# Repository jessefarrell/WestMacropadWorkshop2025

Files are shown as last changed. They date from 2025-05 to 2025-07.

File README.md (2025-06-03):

# WestMacropadWorkshop2025
This repository is intended to guide the user through the design of a small Macropad using KiCAD for schematic capture and PCB layout, fusion 360 for enclosure design, and QMK as the foundation for firmware. Students should be guided through the material by an instructor, there's not enough info for this repository to stand on its own (yet)

<em><strong>IMPORTANT NOTE</STRONG></em> - Bad Symbol
-
I made a <strong>mistake</strong> in the 0_west_symbol library provided during workshop #2. Please <u><strong>follow these steps to correct the NMOS symbol.</strong></u> If you do not complete these steps, pin 3 and 1 of the mosfet will be backwards.

1) Download the corrected symbol library
    - Go to <a href="https://github.com/jessefarrell/WestMacropadWorkshop2025/blob/main/kicad_libraries/0_west_symbols.kicad_sym">design_documents/0_west_symbols.kicad_sym</a> in the github repo and download the file
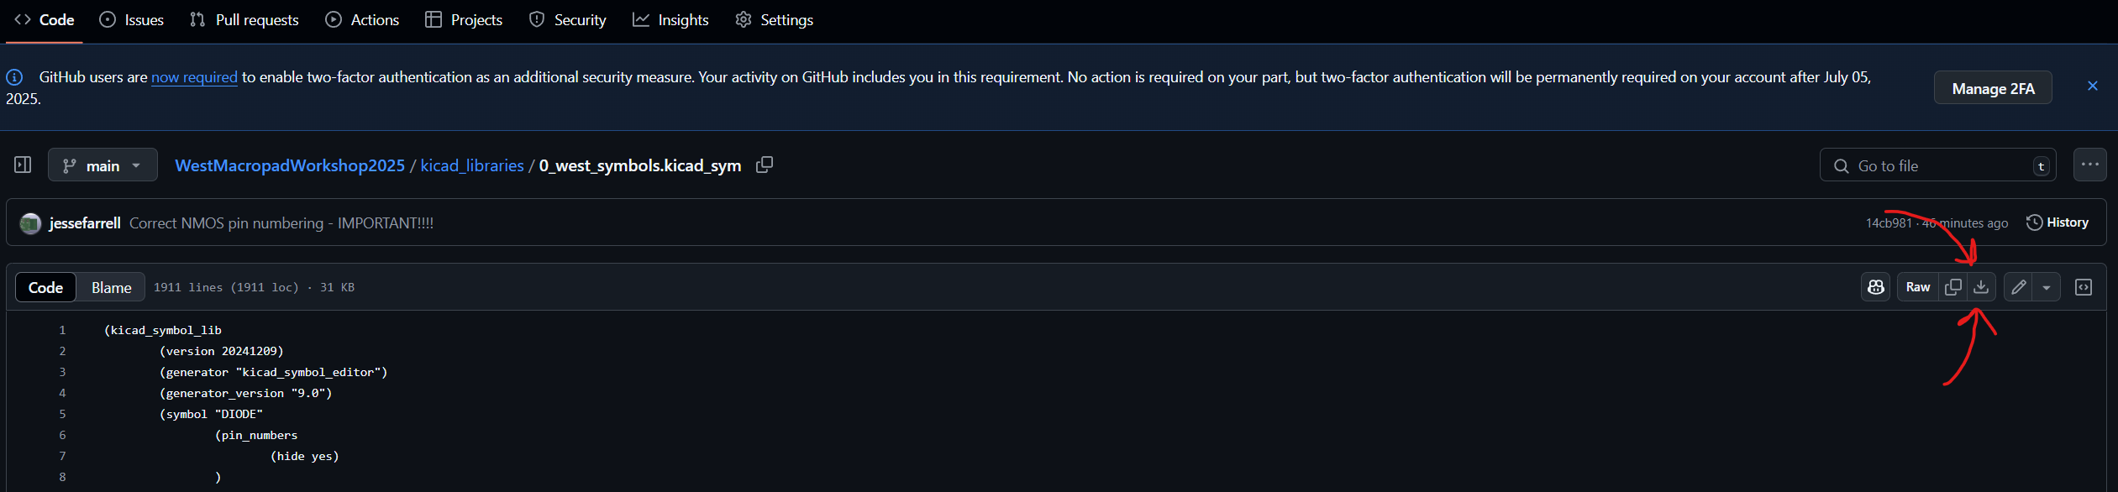
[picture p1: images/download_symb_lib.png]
Download symbol library
    - 
2) Replace <em>0_west_symbols.kicad_sym</em> in your project
    - Navigate to \WestMacropadWorkshop2025\kicad_libraries in your active project directory (not github)
    - Copy the file you downloaded in step 1 into kicad_libraries
    - Select <strong><u>replace the file in the destination</u></strong>
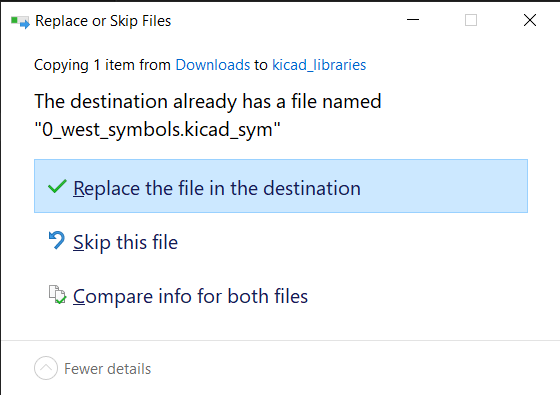
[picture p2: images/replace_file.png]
    - 

3) Sanity Check, & Update Symbol
    - If you've already placed the symbol, you'll have to tell KiCad to reload it
    - To do this <strong>*right-click*</strong> the symbol and go to "Update Symbol" The below window should pop up
    - Select the "Update symbols matching library identifier", and then "Select All" the fields... finally hit <strong>Update</strong>
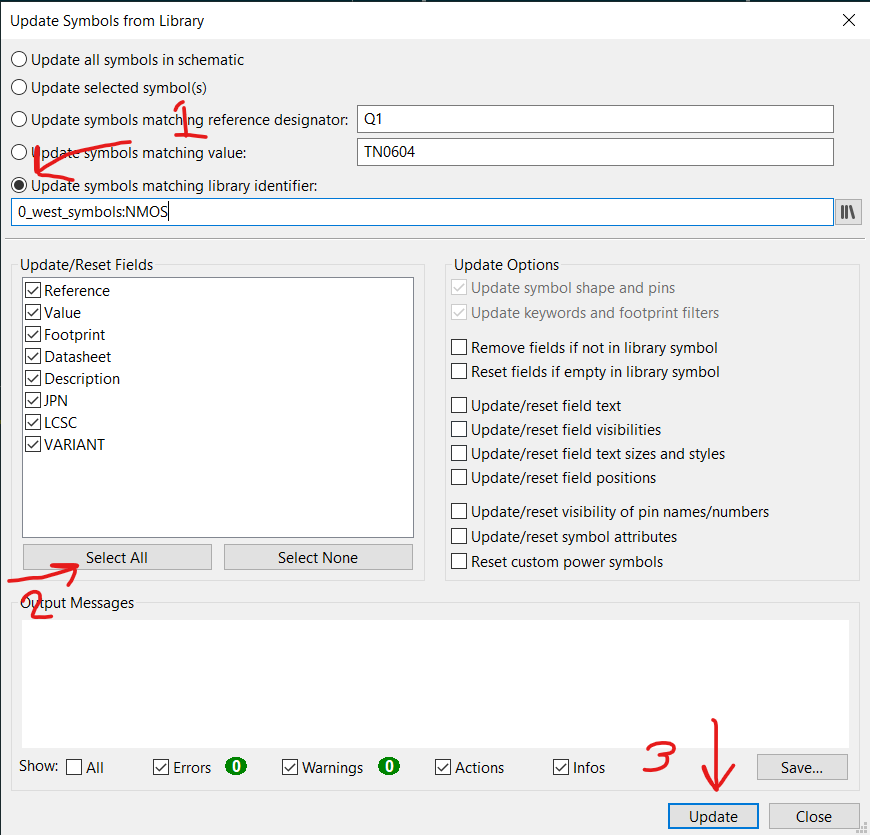
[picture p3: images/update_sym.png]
    - 
    - Once the symbol is updated it should look like this (see below)... pin 3 on top and pin 1 on the bottom 
    - If you odn't see the pin numbers you can enable them using <strong>*right-click*</strong> -> Properties -> Show Pin Numbers
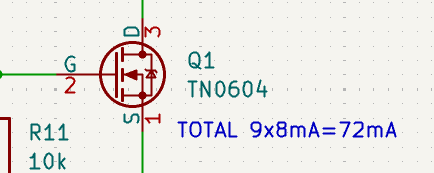
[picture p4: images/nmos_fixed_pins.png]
    - 

Workshop 3 - PCB Layout 
-
> PCB Workshop is primarily outlined in an external document. Several useful files for workshop 3 are stored in this repository.
- Basic Macropad Board Outline - <a href="https://github.com/jessefarrell/WestMacropadWorkshop2025/blob/main/design_documents/Basic_PCB_outline.dxf">/design_documents/Basic_PCB_outline.dxf</a>
    - The "dxf" file is a mechanical file that helps specify locations of critical components for the enclosure... such as key switches, the Pi Pico Development board, and screw holes
- Backup Reference Design - <a href="https://github.com/jessefarrell/WestMacropadWorkshop2025/releases/tag/Workshop%233-Start">Workshop#3 - Blank PCB</a>
    - Hopefully everyone is bringing in their own <em>custom</em> schematic from workshop 2... If not, students can always fall back on the reference design
    - Download the "source code (zip)" from the above link <strong>only if you need to</strong>  
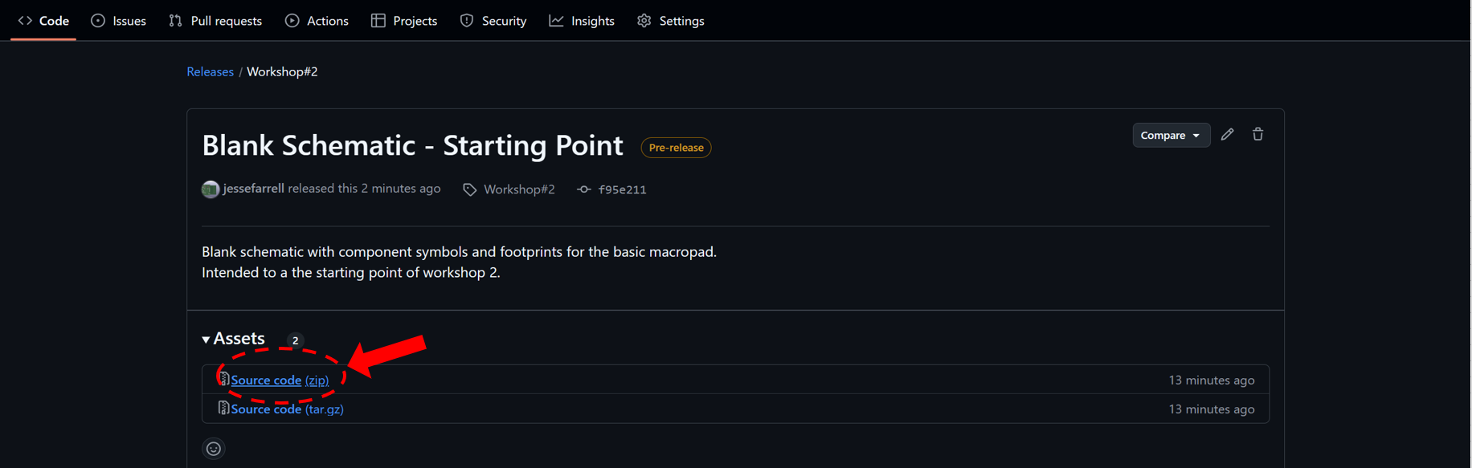
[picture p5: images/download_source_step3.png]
    - 
- New Footprints - <a href="https://github.com/jessefarrell/WestMacropadWorkshop2025/tree/main/kicad_libraries/0_west_footprints.pretty">kicad_libraries/0_west_footprints.pretty</a>
    - I've added some Schneider and WEST logos to the 0_west_footprints library

Workshop 2 - Schematic
-
> Step by step instructions to be followed during the workshop.
1) Copy WestMacropadWorkshop2025 Workshop#2 to your local machine
    - We'll learn more about github & version control later :)
    - Download the "source code (zip)" from here the github repo -> <a href="https://github.com/jessefarrell/WestMacropadWorkshop2025/releases/tag/Workshop%232-start">WestMacropadWorkshop2025</a>
    - KiCad v9 Homepage
    - Extract the contents somewhere on your machine

2) Open **WestMacropadWorkshop2025/west_workshop_2025.kicad_pro**
    - This should automatically launch kicad 9
    - If not launch kicad 9 manually, and then go *File->Open Existing Project* and navigate to the above **kicad_pro** file
3) Double click **west_workshop_2025.kicad_sch** or launch the **Schematic Editor**
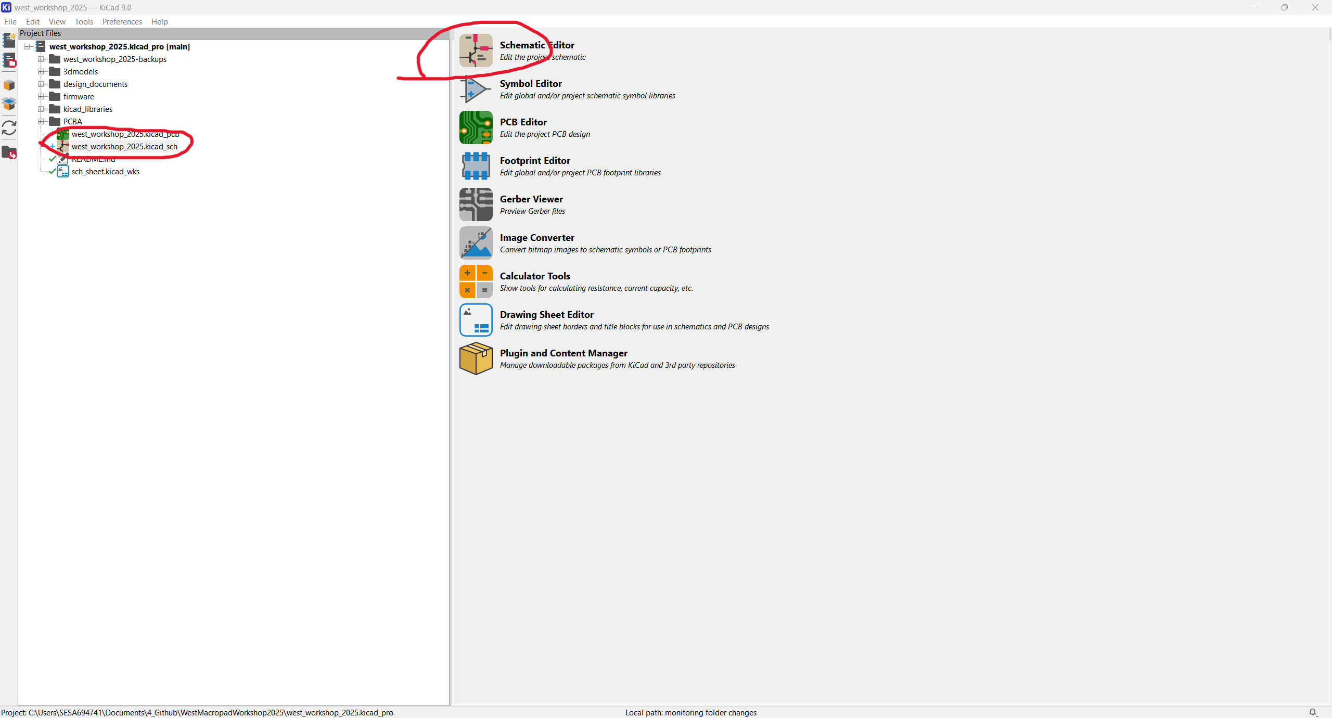
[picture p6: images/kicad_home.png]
KiCad v9 Homepage
    - 

4) Your screen hopfully looks like this. You should be on Kicad v9 or higher.
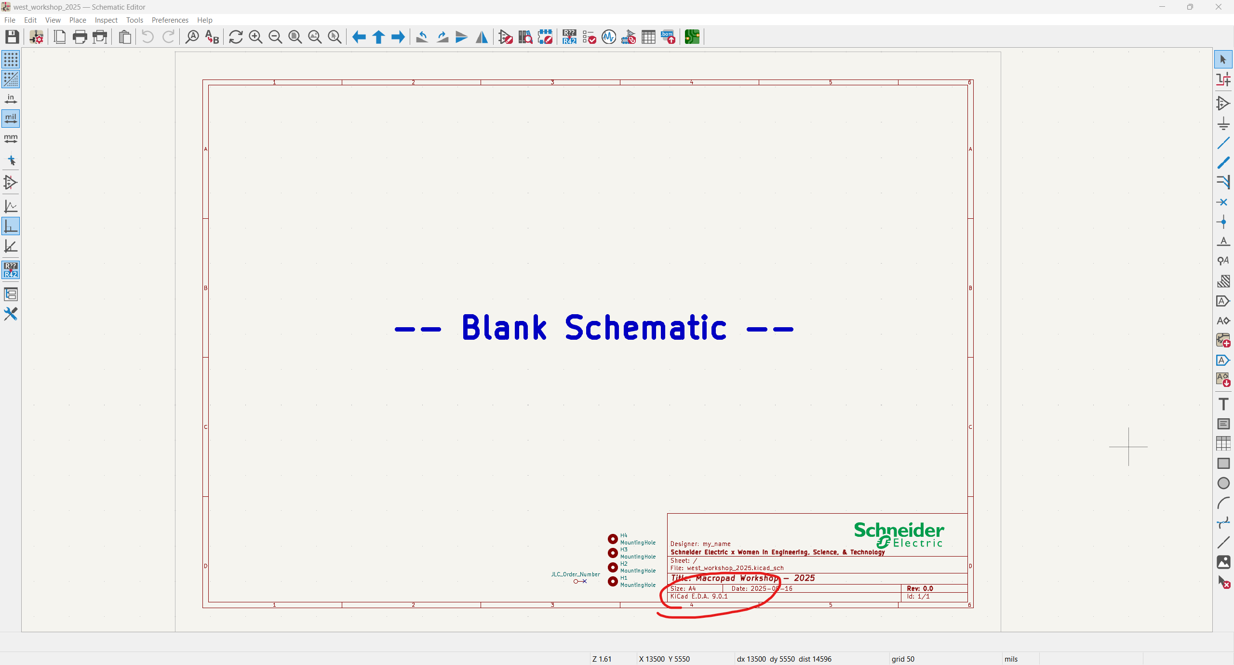
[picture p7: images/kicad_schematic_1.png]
KiCad v9 Schematic
    - 

5) Import WEST libaries (**Optional, but Useful for 3D Visualization**)
    - Symbols and footprints are already configured for the basic macropad
    - Only **the 3D models will be missing** by default
    - If you skip this step now, you may have to do it in workshop 3 or 4
    - First we'll need to import a third party plugin to get the 3d models for the switches
        - Launch the "Plugin and Content Manager"
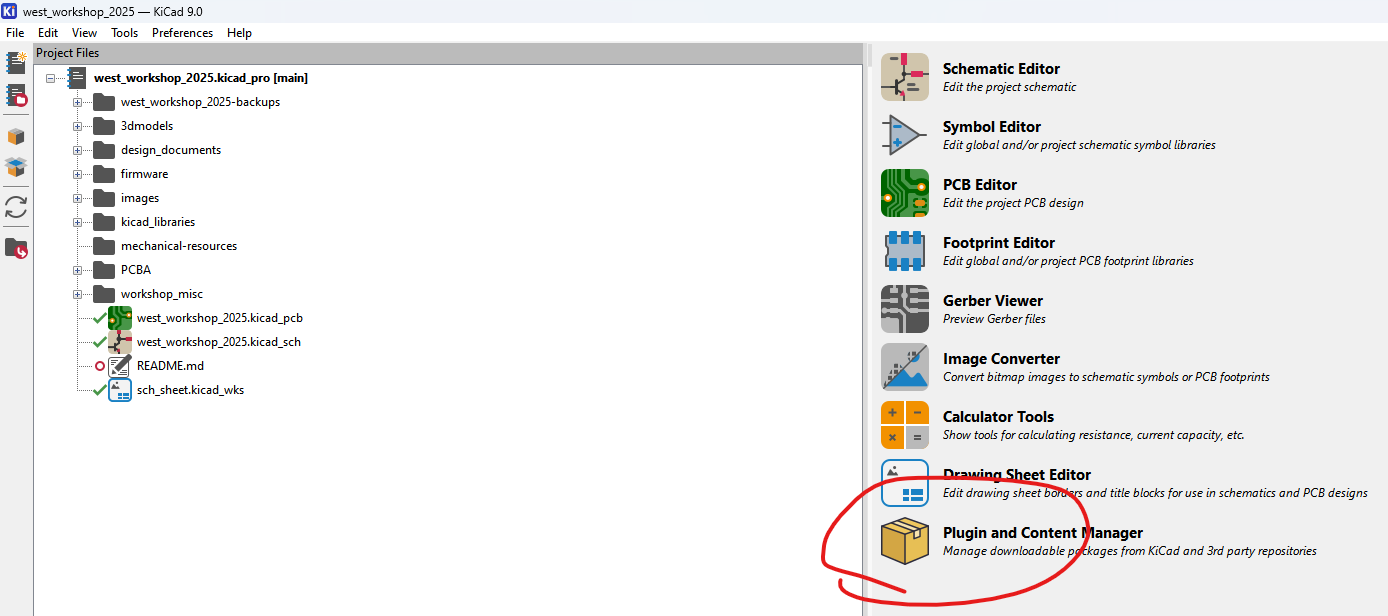
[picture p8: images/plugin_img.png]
        - 
        - Next navigate to "Repository", and "Libraries" shown below. Install the "Keyswitch Kicad Library", and then hit "Apply Pending Changes"
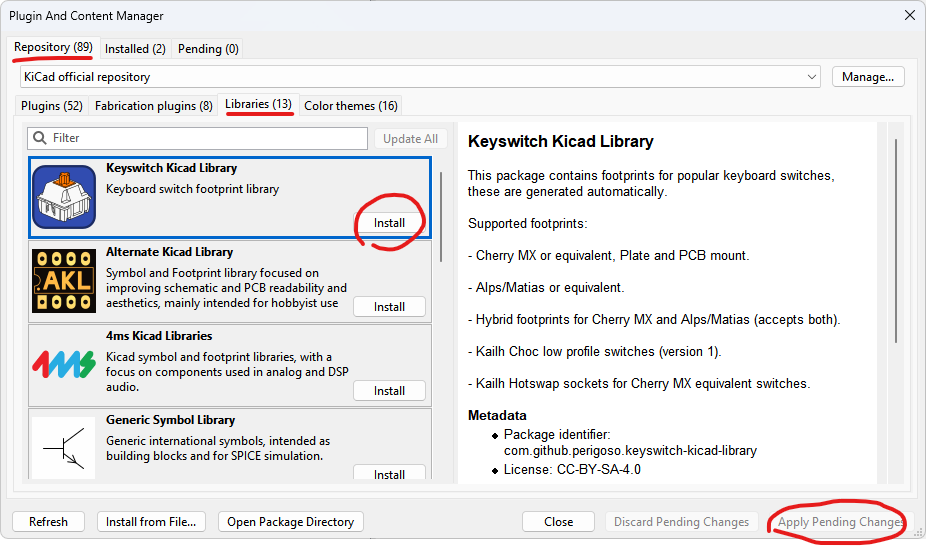
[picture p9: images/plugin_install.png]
        - 
    - Next we're going to go back to the project homepage where we started and launch the **PCB Editor** then go **Preferences->Configure Paths...**
    - Add the following name and path
        - Name: KICAD_USER_3DMODEL_DIR
        - Path: ${KIPRJMOD}\3dmodels
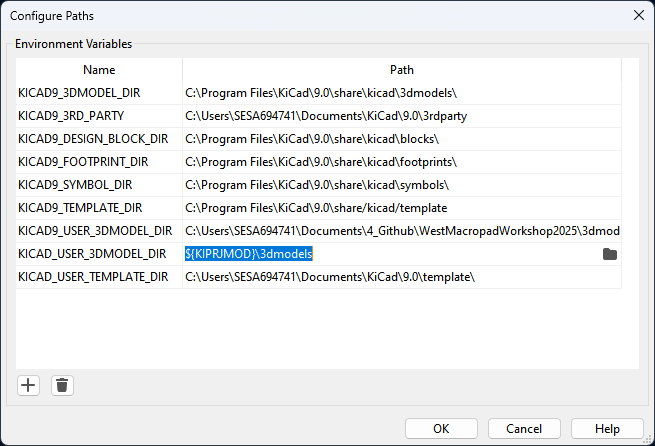
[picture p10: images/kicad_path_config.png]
KiCad v9 Homepage
    - 

6) Place your first symbol
    - Navigate to the **right toolbar** and click the ***"place symbols"*** (the sidways triangle button)
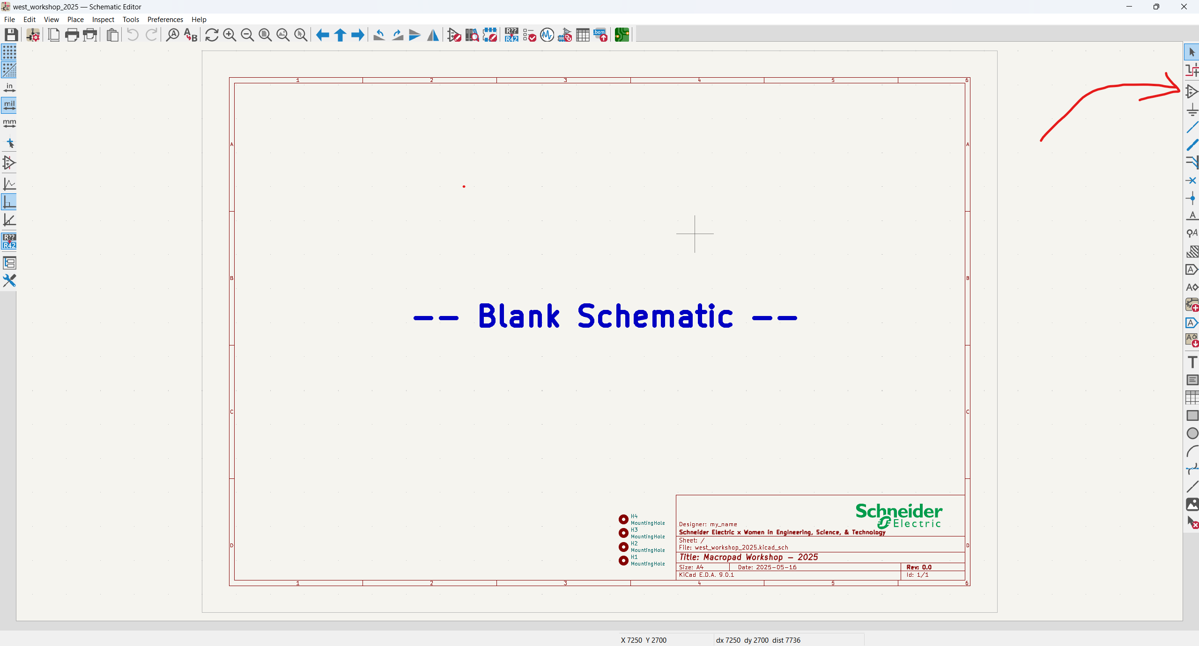
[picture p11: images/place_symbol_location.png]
    - 
    - Your system will need to ***"load symbol libraries"*** the first time you do this... don't worry it only has to do this once
    - Find a random symbol and place it somewhere on the schematic
    - 🎉 First component placed!

7) Get familiar with the symbols we'll be using (place more symbols)
    - Key components have been organized into the **west_symbols libarary**, additional components related to the **advanced** macropad have not be pre configured
    - Raspberry pi pico **@west_symbols/RaspberryPi_Pico**
    - Key Switches **@west_symbols/Switch_Push**
    - Resistors **@west_symbols/Resistor**
    - LED **@west_symbols/LED**
    - MOSFET **@west_symbols/NMOS**

8) Create the diode key matrix discussed in the workshop
    - If you forget what that looks like, checkout the key matrix simulation using falstad ***WestMacropadWorkshop2025\design_documents\simulations***
    - Or take a look at the reference schematic ***WestMacropadWorkshop2025\design_documents\reference_schematic.pdf***
    - NOTE - If you're searching online you might see some schematics where the diodes are flipped compared to ours... this is because the **direction can be managed by QMK**, so long as **every diode is the same direction**

9) Create the backlight driver circuit
    - If you forget what that looks like, checkout the backlight driver simulation using falstad ***WestMacropadWorkshop2025\design_documents\simulations***
    - Or take a look at the reference schematic ***WestMacropadWorkshop2025\design_documents\reference_schematic.pdf***

10) Connect the backlight and matrix to the Pi Pico
    - So long as you connect them to a GPIO, it doesn't matter which specific GPIO you use
    - If you doing something more advanced such as driving a display, **BEWARE** not every GPIO is equivalent

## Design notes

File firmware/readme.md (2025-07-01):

---
---
# Table of Contents
[QMK Workshop Guide](#qmk-workshop-guide)
- [Document Overview](#document-overview)
- [Helpful Links](#helpful-links)
- [QMK Files](#qmk-files)
- [Preliminary Setup](#preliminary-setup)

[1. Setting Up QMK](#1-setting-up-qmk)
- [1.1 Install QMK MSYS](#11-install-qmk-msys)
- [1.2 Prepare Your Build Environment](#12-prepare-your-build-environment)
- [1.3 Confirm Result Looks Good](#13-test-your-build-environment)

[2. One Key Macropad](#2-one-key-macropad)
- [2.1 Create Your New Keyboard](#21-create-your-new-keyboard)
- [2.2 Modify the Code](#22-modify-the-code)
- [2.3 Compile](#23-compile)
- [2.4 Flash the RP2040](#24-flash-the-rp2040)
- [2.5 Test It](#25-test-it)

[3. Basic Macropad](#3-basic-macropad)
- [3.1 Create Your New Keyboard](#31-create-your-new-keyboard)
- [3.2 Add Buttons](#32-add-buttons)
- [3.3 Test the Button Feature](#33-test-the-button-feature)
- [3.4 Add Backlight](#34-add-backlight)
- [3.5 Test the Backlight Feature](#35-test-the-backlight-feature)

[4. Advanced Macropad Features](#4-advanced-macropad-features)
- [4.1 Rotary Encoders](#41-rotary-encoders)
- [4.2 RGB Lighting](#42-rgb-lighting)
- [4.3 OLED Display](#43-oled-display)

[General Steps](#general-steps)
- [Flashing the RP2040](#flashing-the-rp2040)
- [Create a New Keyboard](#creating-a-new-keyboard)

---
---
# QMK Workshop Guide

## Document Overview
This guide will walk you through the process of creating and customizing your own QMK-powered macropad. Whether you're using our basic macropad or bringing your own design, follow along to get started.

<em>NOTE - These instructions are focused on the basic macropad. All pins used in this guide will be based on its [reference schematic](https://github.com/jessefarrell/WestMacropadWorkshop2025/blob/main/design_documents/reference_schematic_A.pdf). Changes <u>will</u> be required if you are not using the basic macropad reference design.</em>

## Helpful Links
* **Overview and Setup**
  * [QMK Setup Tutorial](https://docs.qmk.fm/newbs) – A good starting point/alternative to this document!
  * [Setting Up Your QMK Environment](https://docs.qmk.fm/#/newbs_getting_started) – Environment installation and setup
  * [Basic Keycodes](https://docs.qmk.fm/#/keycodes_basic) – Keycode reference
  * [More Keycodes](https://docs.qmk.fm/keycodes) - Even more keycodes!

* **Advanced Macropad, Useful Links**
  * [QMK RP2040](https://docs.qmk.fm/platformdev_rp2040) - QMK documentation about RP2040 support
  * [QMK Rotary Encoders](https://docs.qmk.fm/features/encoders) - QMK documentation for adding rotary encoders
  * [QMK WS2812](https://docs.qmk.fm/drivers/ws2812) - QMK Documentation for WS2812 (RGB) LEDs
  * [QMK OLED Driver](https://docs.qmk.fm/features/oled_driver) - QMK Documentation for 
  
* **Common QMK Commands**
  * `qmk doctor`
  * `qmk new-keyboard` 
  * `qmk lint -kb 0_se_west/<keyboard_name> -km default`
  * `qmk compile -kb 0_se_west/<keyboard_name> -km default`

## QMK Files
* `readme.md` – Required documentation file
* `keyboard.json` – Used by QMK to configure your keyboard
* `keymap.c` – Defines the keymap, ie what each button "does" on your macropad
* `others...` – QMK projects have many more files, but the above 3x are the main ones we need to interact with regularly

## Preliminary Setup
* Enable **file name extensions** in your file explorer
  * At times we need to rename and modify files, this requiers us to overwrite the file extensions as well... if you do not enable this feature you might inadvertently create a file "`config.h.txt`" when you meant to create "`config.h`"
  * Instructions for [Windows 10](https://support.microsoft.com/en-us/windows/common-file-name-extensions-in-windows-da4a4430-8e76-89c5-59f7-1cdbbc75cb01)
  * Instructions for [Windows 11](https://www.howtogeek.com/205086/beginner-how-to-make-windows-show-file-extensions/)
  * Instructions for [Mac](https://support.apple.com/en-eg/guide/mac-help/mchlp2304/mac)
---
---
# 1. Setting Up QMK
The following steps are based on QMK's [setup documentation](https://docs.qmk.fm/newbs_getting_started). For more details please see their documentation.

## 1.1 Install QMK MSYS
> <strong>This should already be done before the workshop since it's a slow process.</strong>
* Go to [QMK MSYS](https://msys.qmk.fm/)
* Click the "Latest version" button
* Download and install the EXE

## 1.2 Prepare Your Build Environment
> <strong>Same as above, this was hopefully done before the workshop</strong>
* Launch QMK MSYS and run:

  ```bash
  qmk setup
  ```
* Accept any prompts

## 1.3 Test Your Build Environment
- Run the following command in QMK MSYS
  ```bash
  qmk compile -kb clueboard/66/rev3 -km default
  ```
- If you run into a permissions issue, relaunch QMK MSYS as admin (right click Run As Administrator)
- Depnding on your computer, this step can take several minutes to complete

## 1.4 Confirm Result Looks Good
- Once done you should see something similar to this output... 
- <strong>Reach out if you don't see this response.</strong>
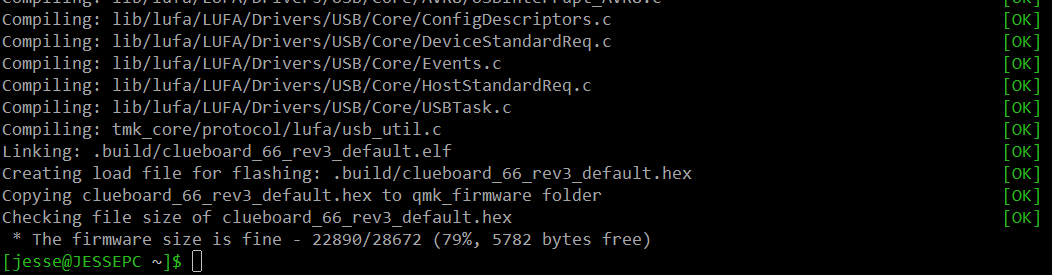
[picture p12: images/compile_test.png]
Initial Compile Output
- <!--  -->

---
---
# 2. One Key Macropad
The easiest macropad we can make, not to mention one which requires very few components, is a single key macropad! This is an easy way to confrim that your development board (the Raspberry Pi Pico) is okay, and it helps us confirm that your build environment is working. 

## 2.1 Create Your New Keyboard
- See [How to Setup a New QMK Keyboard](#creating-a-new-keyboard) for details.

## 2.2 Modify the Code
We only need to modify <strong>two files</strong> to setup the single key keyboard. These files are `keyboard.json`, and `keymap.c`.

### 2.2.1 Modify `keyboard.json`
We need to do two things in keyboard.json.
1) Define the "matrix_pins"
2) Define the "layouts"

**BEFORE**
```json
"matrix_pins": {
    "cols": ["C2", "C2", "C2", "C2"],
    "rows": ["D1", "D1", "D1", "D1"]
},
```
```json
"layout": [
    {"matrix": [0, 0], "x": 0, "y": 0},
    {"matrix": [0, 1], "x": 1, "y": 0},
    {"matrix": [0, 2], "x": 2, "y": 0},
    {"matrix": [0, 3], "x": 3, "y": 0},
    {"matrix": [1, 0], "x": 0, "y": 1},
    {"matrix": [1, 1], "x": 1, "y": 1},
    {"matrix": [1, 2], "x": 2, "y": 1},
    {"matrix": [1, 3], "x": 3, "y": 1},
    {"matrix": [2, 0], "x": 0, "y": 2},
    {"matrix": [2, 1], "x": 1, "y": 2},
    {"matrix": [2, 2], "x": 2, "y": 2},
    {"matrix": [2, 3], "x": 3, "y": 2},
    {"matrix": [3, 0], "x": 0, "y": 3},
    {"matrix": [3, 1], "x": 1, "y": 3},
    {"matrix": [3, 2], "x": 2, "y": 3},
    {"matrix": [3, 3], "x": 3, "y": 3}
]
```

**AFTER**

```json
  "matrix_pins": {
    "cols": ["GP14"],
    "rows": ["GP15"]
  },
```
```json
"layout": [
  { "matrix": [0, 0], "x": 0, "y": 0 }
]
```

### 2.2.2 Modify `keymap.c`
This is where we will define what the key actually does. To do this you'll need to modify the `LAYOUT`. In the example below we're modifying the key to send (`KC_A`), but you can use any key you'd like.

**BEFORE**
```c++
[0] = LAYOUT(
    KC_P7,   KC_P8,   KC_P9,   KC_PSLS,
    KC_P4,   KC_P5,   KC_P6,   KC_PAST,
    KC_P1,   KC_P2,   KC_P3,   KC_PMNS,
    KC_P0,   KC_PDOT, KC_PENT, KC_PPLS
)
```

**AFTER**
```c++
[0] = LAYOUT(
    KC_A // Change to any keycode you want
)
```

### 2.2.3 Add Autoshift (*Optional*)
Auto shift is a cool feature supported by QMK. If we enable the autoshift feature for our single key macropad, when we **hold down** the key it will send a capitalized version of the key. So instead of `a` we should see `A` in our case.

- Create a file named `rules.mk` inside your `keymaps/default` folder
- Add the following line to that new `rules.mk` file
```bash
AUTO_SHIFT_ENABLE = yes
```

## 2.3 Compile
The keyboard name and path is just an example.
```bash
qmk compile -kb 0_se_west/<your_keyboard> -km default
```

## 2.4 Flash the RP2040
Flash your Raspberry Pi Pico as per the [flashing instructions](#flashing-the-rp2040).

## 2.5 Test It!!!
- Launch a text editor (notepad, ect)
- Use a resistor to temporarily connect GPIO15 and GPIO14 on the Raspbery Pi Pico. 
- You should see the character you defined in [2.2.2](#1b-modify-keymapc) appear in your text editor
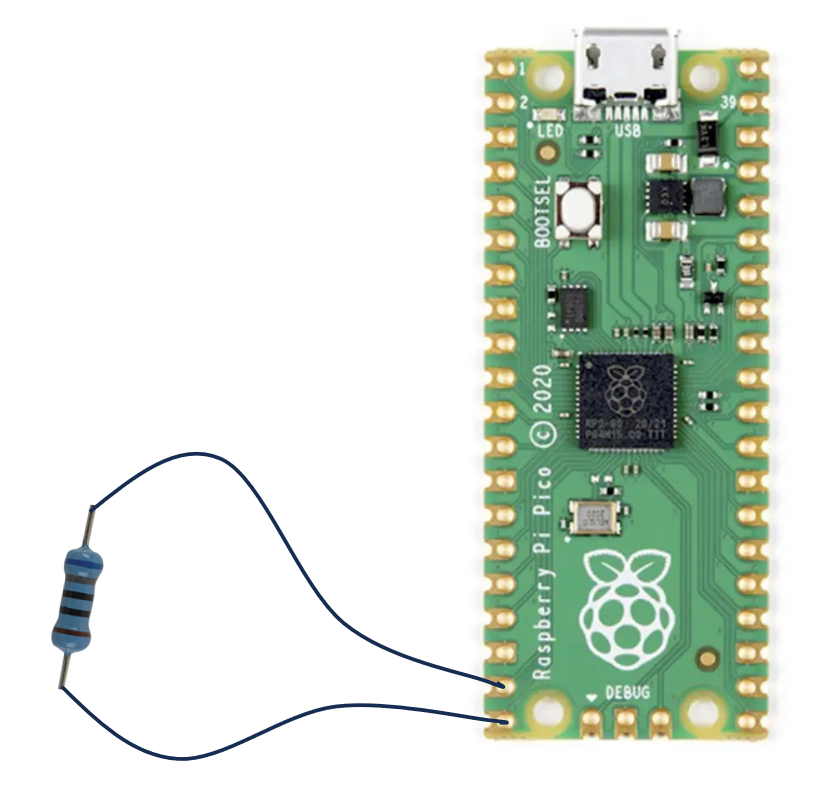
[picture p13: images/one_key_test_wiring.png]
Test One Key
- 

---
---
# 3. Basic Macropad
The basic macropad is much more complex than the [One Key Macropad](#2-one-key-macropad). It's recommended that you test your code frequently, by compiling your code and [flashing](#flashing-the-rp2040) the RP2040.

The basic macropad will be designed in two steps or iterations...
- **Iteration 1** - Adding the nine buttons, completed example here -> [LINK](https://github.com/jessefarrell/WestMacropadWorkshop2025/tree/main/firmware/FW%20files%20-%20basic%20reference%20-%20iteration%201/demo3x3)
  - This is steps `3.1 to 3.3` (including all sub-sections)
- **Iteration 2** - Adding backlight support, completed example here -> [LINK](https://github.com/jessefarrell/WestMacropadWorkshop2025/tree/main/firmware/FW%20files%20-%20basic%20reference%20-%20iteration%202/demo3x3)
  - This is steps `3.4 to 3.5` (including all sub-sections)

## 3.1 Create Your New Keyboard
- See [How to Setup a New QMK Keyboard](#creating-a-new-keyboard) for details.

## 3.2 Add Buttons
This step is similar to [2.2](#22-modify-the-code), we just have more keys... similar to before we'll need to modify two files `keyboard.json`, and `keymap.c`.

### 3.2.1 Modify `keyboard.json`

#### `matrix_pins`
- First let’s tell QMK which GPIO are connected to which column and row. We can do this by modifying the `matrix_pins` “cols” and “rows” data. For the basic macropad we used GPIO0 to GPIO5. So, we made the following change. 

  **BEFORE**
  ```json
  "matrix_pins": {
      "cols": ["C2", "C2", "C2", "C2"],
      "rows": ["D1", "D1", "D1", "D1"]
  },
  ```

  **AFTER**
  ```json
  "matrix_pins": {
      "cols": ["GP0", "GP1", "GP2"],
      "rows": ["GP3", "GP4", "GP5"]
  },
  ```

#### `layout`
- Next modify the layouts field. This tells qmk where the keys are located on your macropad. Also notice the template QMK generated for us what 4x4 and not 3x3.

  **BEFORE**
  ```json
  "layout": [
      {"matrix": [0, 0], "x": 0, "y": 0},
      {"matrix": [0, 1], "x": 1, "y": 0},
      {"matrix": [0, 2], "x": 2, "y": 0},
      {"matrix": [0, 3], "x": 3, "y": 0},
      {"matrix": [1, 0], "x": 0, "y": 1},
      {"matrix": [1, 1], "x": 1, "y": 1},
      {"matrix": [1, 2], "x": 2, "y": 1},
      {"matrix": [1, 3], "x": 3, "y": 1},
      {"matrix": [2, 0], "x": 0, "y": 2},
      {"matrix": [2, 1], "x": 1, "y": 2},
      {"matrix": [2, 2], "x": 2, "y": 2},
      {"matrix": [2, 3], "x": 3, "y": 2},
      {"matrix": [3, 0], "x": 0, "y": 3},
      {"matrix": [3, 1], "x": 1, "y": 3},
      {"matrix": [3, 2], "x": 2, "y": 3},
      {"matrix": [3, 3], "x": 3, "y": 3}
  ]
  ```

  **AFTER**
  ```json
  "layout": [
      {"matrix": [0, 0], "x": 0, "y": 0},
      {"matrix": [0, 1], "x": 1, "y": 0},
      {"matrix": [0, 2], "x": 2, "y": 0},
      {"matrix": [1, 0], "x": 0, "y": 1},
      {"matrix": [1, 1], "x": 1, "y": 1},
      {"matrix": [1, 2], "x": 2, "y": 1},
      {"matrix": [2, 0], "x": 0, "y": 2},
      {"matrix": [2, 1], "x": 1, "y": 2},
      {"matrix": [2, 2], "x": 2, "y": 2}
  ]
  ```

#### `diode_direction`

  - Finally, you might need to change the “diode_direction” for your macropad. The diodes on our basic macropad “point” from row to column. So we’ll make the following change. 
    
    **BEFORE**
    ```json
    "diode_direction": "COL2ROW",
    ```
    
    **AFTER**
    ```json
    "diode_direction": "ROW2COL",
    ```
### 3.2.2 Modify `keymap.c`

#### `LAYOUT()`
- We need to tell QMK what each of these nine keys should "do" by defining the LAYOUT in keymap.c. Have a look at the all the [keycodes available](https://docs.qmk.fm/keycodes).
    ```C++
    [0] = LAYOUT(
		KC_1,   KC_2,   KC_3,
        KC_4,   KC_5,   KC_6,
        KC_7,   KC_8,   KC_9
    )
    ```

## 3.3 Test the "Button" Feature

#### 3.3.1 Compile:
- Run the following command. 
- Reminder depending on where you put your keyboard you might not need the path `0_se_west`

  ```bash
  qmk compile -kb 0_se_west/<your_keyboard> -km default
  ```
### 3.3.2 Flash the RP2040
- Flash your Raspberry Pi Pico as per the [flashing instructions](#flashing-the-RP2040).

### 3.3.3 Test It!!!
- Launch a text editor (notepad, ect)
- Press some buttons, and confirm they appear on the screen

## 3.4 Add Backlight
There are a few different types of lighting effects you might want to use on your macropad. The following process is how I setup the “breathing” effect on the basic macropad. Note that this will not work on RGB lights, its intended for a single colour LED.

### 3.4.1 Modify `keyboard.json`

- We need to give QMK some information about our backlight. For the basic macropad that included the following changes to `keyboard.json`.
- Please note that `features` already exists (we are just adding `"backlight":true,`), whereas `backlight` is a completely new item

  ```json
  "features": {
      "backlight": true,
      "bootmagic": true,
      "extrakey": true,
      "mousekey": true,
      "nkro": true
  },
  ```
  
  ```json
  "backlight": {
      "breathing": true,
      "on_state": 1,
      "pin": "GP6",
      "default":{ "breathing":true }
  },
  ```

### 3.4.2 Modify `keymap.c`
- The following changes make it so that holding KEY1 enables the _BACKLIGHT layer
- While holding KEY1 we can use the other keys to toggle the backlight and change its brightness
- *NOTE - The below code replaces all the contents inside keymap.c*
  ```c++
  #include QMK_KEYBOARD_H

  // define layers
  #define _NUM 0
  #define _BACKLIGHT 1

  // define custom keycodes
  #define KC_WEST_1 LT(_BACKLIGHT, KC_1)

  const uint16_t PROGMEM keymaps[][MATRIX_ROWS][MATRIX_COLS] = {
      /*
      * ┌───┬───┬───┐
      * │ 1 │ 2 │ 3 │
      * ├───┼───┼───┤
      * │ 4 │ 5 │ 6 │
      * ├───┼───┼───┤
      * │ 7 │ 8 │ 9 │
      * └───┴───┴───┘
      */
      [_NUM] = LAYOUT(
          KC_WEST_1,   KC_2,   KC_3,
          KC_4,   KC_5,   KC_6,
          KC_7,   KC_8,   KC_9
      ),
      [_BACKLIGHT] = LAYOUT(
          _______,QK_BACKLIGHT_TOGGLE,   QK_BACKLIGHT_STEP,
          QK_BACKLIGHT_UP,   QK_BACKLIGHT_DOWN,   QK_BACKLIGHT_TOGGLE_BREATHING,
          KC_7,   QK_BACKLIGHT_ON,   QK_BACKLIGHT_OFF
      )
  };
  ```

### 3.4.3 Add New Supporting Files

- Create these 3 files in `0_se_west/<your_keyboard>`, paste the content into the file then save and close the file. <em>NOTE – the copyright comment is done to satisfy the linting tool.</em>
- These three files are needed to configure the RP2040's PWM peripheral... it's a little clunky

**`halconf.h`**
```c
// Copyright 2020 xxx
#pragma once
#include_next <halconf.h>
#define HAL_USE_PWM TRUE
```

**`mcuconf.h`**

```c
// Copyright 2020 xxx 
#pragma once
#include_next <mcuconf.h>
#undef RP_PWM_USE_PWM3
#define RP_PWM_USE_PWM3 TRUE
```

**`config.h`**:

```c
// Copyright 2020 xxx
#pragma once
#include_next <config.h>
#define BACKLIGHT_PWM_DRIVER PWMD3
```

## 3.5 Test the Backlight Feature
- Repeat steps [3.3.1](#331-compile), [3.3.2](#332-flash-the-rp2040), and [3.3.3](#333-test-it)
- Note whether the backlight works as expected...

---
---
# 4. Advanced Macropad Features
- Since everyone's advanced macropad looks different, this section will be left more generic. For details on each of the features on our advanced design see sections [4.1](#41-rotary-encoders), [4.2](#42-rgb-lighting), and [4.3](#43-oled-display).
- If you just want to see what **WE DID** for the advanced macropad, have a look at the [advanced macropad code](https://github.com/jessefarrell/WestMacropadWorkshop2025/tree/main/firmware/0_se_west/advanced).
- As a reminder our advanced macropad included a 3x3 key matrix, a rotary encoder with an integrated button, and an OLED display which displayed the Schneider Electric logo.
- **It is strongly recommended that you test each feature as you add them.** For example you could first check the rotary encoder works as expected, then attempt to add the RGB, and then the display (testing as you go).
- *NOTE - If one of the files does not exist, you might need to create it first... please reference the [advanced macropad code](https://github.com/jessefarrell/WestMacropadWorkshop2025/tree/main/firmware/0_se_west/advanced) for where to create this new file*

## 4.1 Rotary Encoders
- Review [QMK's encoder documentation](https://docs.qmk.fm/features/encoders)
- For the advanced design we enabled the feature by changing `config.h`, `keyboard.json`, `keymap.c`, and `rules.mk`.

### 4.1.1 Update `config.h`
- Add the following lines to your config.h file
- For details about each line of code please refer to [QMK's documentation](https://docs.qmk.fm/features/encoders)
  ```c++
  // Rotary Encoder Support
  #define ENCODER_RESOLUTION 5
  #define ENCODER_MAP_KEY_DELAY 10
  #define ENCODER_DIRECTION_FLIP
  ```

### 4.1.2 Update `keyboard.json`
- Add the following lines to your keyboard.json file
- This also could have been done in `config.h` (I believe)
  ```c++
  "encoder": {
      "rotary": [
          {"pin_a": "GP27", "pin_b": "GP28"}
      ]
  },
  ```

### 4.1.3 Update `keymap.c`
- Add the following lines to your keymap.c file
- This is where you can define what the rotary encoder does
- I used `KC_VOLD` and `KC_VOLU` (volume up and down), see full list of [keycodes here](https://docs.qmk.fm/keycodes)
  ```c++
  #ifdef ENCODER_MAP_ENABLE
  const uint16_t PROGMEM encoder_map[][NUM_ENCODERS][NUM_DIRECTIONS] = {
    [0] = { ENCODER_CCW_CW(KC_VOLD, KC_VOLU) },
  };
  #endif
  ```

### 4.1.4 Update `rules.mk`
- Add the following lines to your rules.mk file
  ```bash
  # Rotary encoder setup
  ENCODER_MAP_ENABLE = yes
  ENCODER_ENABLE = yes
  ```

### 4.1.5 Adding the push button
- The rotary encoder used on the advanced design included a push button
- To add the push button on the advanced design I had to update `keyboard.json` and `keymap.c`
- Note the advanced design **did not use a diode matrix** (instead it used direct connections to each switch) so it **will look different on your design**
- In `keyboard.json` the matrix had to be symmetric so I added `null` switches... `GP25` was the rotary encoder button in my case
  ```c++
  "matrix_pins": {
      "direct":[  ["GP25", null, null],
                  ["GP0", "GP3", "GP9"],
                  ["GP1", "GP4", "GP8"],
                  ["GP2", "GP5", "GP6"]]
  },
  ```
- Next I added the key in my `keymap.c`, `KC_1`
  ```c++
  [0] = LAYOUT(
      KC_1,
      UG_NEXT,   KC_2,   KC_3,
      KC_4,   KC_5,   KC_6,
      KC_7,   KC_8,   KC_9
  )
  ```

### 4.1.6 Test the Feature
- Compile your code (see previous steps)
- Check that the rotary encoder 

## 4.2 RGB Lighting
- Review [QMK's WS2812 documentation](https://docs.qmk.fm/drivers/ws2812), this is the LED everyone should have used (though QMK supports more)
- There's two ways we used to control the RGB lighting... ["rgb_matrix"](https://docs.qmk.fm/features/rgb_matrix) and ["rgblight"](https://docs.qmk.fm/features/rgblight)
- Either method will work, though I ended up using the `rgblight` feature for my design
- I'll document what **WE** did shortly... for now though I recommend doing some reading and referring to the [advanced macropad code](https://github.com/jessefarrell/WestMacropadWorkshop2025/tree/main/firmware/0_se_west/advanced)

### 4.2.1 Choose One `rgblight` or `rgb_matrix`
- In general I'd recommend you try to make `rgb_matrix` work, but please take a look at the above documentation
- I used the `rgblight` feature on my design because I was struggling isolating the two "zones" of my RGB using `rgb_matrix` (this is likely do-able even with `rgb_matrix` but I wasn't able to figure it out in time)
- You cannot try to implement both features, choose one, test it, and see if it works for your keyboard

### 4.2.2 `rgb_matrix` Setup
- To enable this feature I had to modify `keyboard.json`, and `rules.mk`.

**Update `keyboard.json`**
- Under "features" add `"rgb_matrix": true,`
```json
"features": {
    "bootmagic": true,
    "command": false,
    "console": false,
    "extrakey": true,
    "mousekey": true,
    "rgb_matrix": true,
    "nkro": true
},
```
- Add the below code to keyboard.json... 
- You might need to change the `"layout"` to match your keyboard, and you might need to change what `"pin"` is connected to your RGB LED.
- Notice the driver we are using is `"ws2812"`, this is the RGB LED we used :)
```json
"rgb_matrix":{
    "animations":{
        "breathing": true
    },
    "driver":"ws2812",
    "layout": [
        {"matrix": [0, 0], "x": 0, "y": 0, "flags": 4},
        {"matrix": [0, 1], "x": 112, "y": 0, "flags": 4},
        {"matrix": [0, 2], "x": 224, "y": 0, "flags": 4},
        {"matrix": [1, 0], "x": 0, "y": 21, "flags": 4},
        {"matrix": [1, 1], "x": 112, "y": 21, "flags": 4},
        {"matrix": [1, 2], "x": 224, "y": 21, "flags": 4},
        {"matrix": [2, 0], "x": 0, "y": 42, "flags": 4},
        {"matrix": [2, 1], "x": 112, "y": 42, "flags": 4},
        {"matrix": [2, 2], "x": 224, "y": 42, "flags": 4}
    ]

},
"ws2812": {
    "pin": "GP10",      <--- CHANGE ME
    "driver": "vendor"
},
```
- I struggled to enable the RGB by default so I ended up assigning the `UG_NEXT` (underglow next) to one of the keys on my keyboard
- This works for a quick test, but I'd recommend you try and use the layer feature like we did in [3.4.2](#342-modify-keymapc) for your final design

**Update `rules.mk`**
- Add the following line, to tell QMK to load the necessary driver
```
WS2812_DRIVER_REQUIRED = yes
```

### 4.2.3 `rgblight` Setup
- In general I recommend you try to implement `rgb_matrix` instead of `rgblight`, but just for completeness I'll add some notes about `rgblight` setup below
- I used this feature on the advanced keyboard, so if you'd like you can reference its code [here](https://github.com/jessefarrell/WestMacropadWorkshop2025/tree/main/firmware/0_se_west/advanced), but beware you won't be able to directly copy the code due to hardware differences
- To setup `rgblight` I modified `keyboard.json`, `keymap.c`, and `proto.c` (my keyboards name was proto, hence proto.c)

**Update `keyboard.json`**
- Add ` "rgb_matrix": true,` under the `"features"` section. (I have some extra features enabled you might not need)
```json
"features": {
    "bootmagic": true,
    "command": false,
    "console": false,
    "extrakey": true,
    "encoder": true,
    "oled": true,
    "mousekey": true,
    "rgblight": true,
    "nkro": true
},
```
- Add the following to define the RGB light
- Note several section labeled `<--- CHANGE ME`, might be different for your setup
```json
"rgblight":{
    "led_count": 13,        <--- CHANGE ME
    "animations":{
        "breathing": true
    },
    "driver":"ws2812",
    "default":{
        "animation": "breathing",
        "val": 255,
        "sat": 255,
        "hue": 64
    }
},
"ws2812": {
    "pin": "GP10",          <--- CHANGE ME
    "driver": "vendor"
},
```

**Update `keymap.c`**
- On my keyboard I had two "zones", one zone was LED 0 to 9, the other was 10 to 13
- I wanted the first zone to host various RGB animations/effects, and I wanted the second (10 to 13) to e static
- To do this I added the following function to my `keymap.c`

```c++
void keyboard_post_init_user(void) {
  // Manually update the defaults in keyboard.json
  // This shouldn't technically be required, but it fixed an issue on my keyboard
  eeconfig_update_rgblight_default();

  // Set RGB effect range, LED 0 to 9
  rgblight_set_effect_range(0, 9); 

  // Apply static color to remaining LEDs
  rgblight_setrgb_range(0, 60, 5, 9, 13);
}
```

**Add `<keyboard_name>.c`**
- Create a file in the same folder as `keyboard.json`, name the file `<your_keyboard_name>.c`
- In my case my keyboard's name was `proto` so the file I created was `proto.c`
- Add the below contents to your new file...

```C++
// Copyright 2020 xxx 
#include "quantum.h"
#ifdef RGBLIGHT_ENABLE
#endif
```

## 4.3 OLED Display
- Review [QMK's OLED documentation](https://docs.qmk.fm/features/oled_driver), the type of display everyone should be using is an SSD1306 based 128x32 OLED
- For the advanced design we enabled the feature by changing `config.h`, `mcuconf.h`, `keyboard.json`, `keymap.c`, and `rules.mk`.
- I'll document what **WE** did shortly... for now though I recommend doing some reading and referring to the [advanced macropad code](https://github.com/jessefarrell/WestMacropadWorkshop2025/tree/main/firmware/0_se_west/advanced)

**Update `config.h`**
- We need to define the driver, I2C address, display size, and we need to assign GPIO's.
- Do this by adding the following to `config.h`... lines labeled `<--- CHANGE ME` might require modification for your system
- Beware you can't assign SCL and SDA at a whim, reference the [RP2040 datasheet](https://datasheets.raspberrypi.com/rp2040/rp2040-datasheet.pdf) (section 1.4.3) for valid configurations

```c++
// OLED Setup
#define I2C_DRIVER I2CD0            //<--- CHANGE ME
#define I2C1_SCL_PIN GP13           //<--- CHANGE ME
#define I2C1_SDA_PIN GP12           //<--- CHANGE ME
#define OLED_DISPLAY_ADDRESS 0x3C
#define OLED_DISPLAY_128X32
```

**Update (or create) `mcuconf.h`**
- This is more driver configuration... there's likely some redundant setup here
- For example we already declared `I2C_DRIVER I2CD0` in `config.h`
```c++
#pragma once

#include_next <mcuconf.h>

#undef RP_I2C_USE_I2C0
#define RP_I2C_USE_I2C0 TRUE

#undef RP_I2C_USE_I2C1
#define RP_I2C_USE_I2C1 FALSE
```

**Update `keyboard.json`**
- Add `"oled": true,` under the supported `features`
- Beware, you might have some different features then me, this is just an example
```json
"features": {
    "bootmagic": true,
    "command": false,
    "console": false,
    "extrakey": true,
    "encoder": true,
    "oled": true,         <--- Add Me
    "mousekey": true,
    "rgb_matrix": true,
    "nkro": true
},
```

**Update `rules.mk`**
- Even more driver setup!
- Add the following to your `rules.mk` file
```make
# OLED setup
OLED_ENABLE = yes
OLED_DRIVER = ssd1306
OLED_TRANSPORT = i2c
```

**Update `keymap.c`**
- Here's where you get to define the actual *image* that your macropad will display
- First we'll add the code, then I'll detail how to **convert an image** to a format QMK supports
- Add the following to the bottom of `keymap.c`
```c++
static void render_logo(void) {
  static const char PROGMEM qmk_logo[] = {
    // Image Data Here!!!
  };

  oled_write_raw_P(qmk_logo, sizeof(qmk_logo));
}

bool oled_task_user(void) {
  render_logo();
  return false;
}
```
- Next find an image you'd like to use (make sure it'll fit reasonably on our tiny 128x32 display)
- We'll use [image2cpp](https://javl.github.io/image2cpp/) to help us convert our image
1) Select Image -> **choose files** and select your desired file
2) Image Settings -> *watch* the preview window while you make these changes
- Canvas Size(s): 128 x 32
- Background Color: Black
- Invert Image Colors: *optional*
- Scaling: scale to fit, keeping proportions
- Brightness: play with this value until the preview looks good
- **All other Image Settings, depend on your setup**
3) Output
- Code Output Format: Plain bytes
- Draw Mode: Vertical: 1 bit per pixel (!!!REQUIRED!!!)
4) Copy Output
5) Paste the data into our `keymap.c` file at `// Image Data Here!!!`

- Compile your project and check that the display looks correct

---
---
# General Steps

## Flashing the RP2040

**Manual Upload**
```bash
qmk compile -kb 0_se_west/<keyboard_name> -km default
```
> NOTE - If you didn't place your keyboard into a specific folder you can ignore the "`0_se_west/`" part of the command

1. Locate your compiled `.uf2` file in `qmk_firmware/.build` 
    - Note, the default path is `c:/Users/<name>/qmk_firmware/.build`)
2. Hold `BOOTSEL` (the ONLY button on the development board) and plug a USB into the Raspberry Pi Pico
3. Release `BOOTSEL`
4. A new drive `RPI-RP2` should appear on your computer
5. Drag and drop the `.uf2` file into this drive
6. The drive will auto-eject when flashing completes

**Using the Flash Command**
```bash
qmk flash -kb 0_se_west/<keyboard_name> -km default
```
1. Hold `BOOTSEL` (the ONLY button on the development board) and plug a USB into the Raspberry Pi Pico
2. Release `BOOTSEL`
3. The `RPI-RP2` drive should appear on your system, **no action is needed**.
4. Once the tool has finished compiling it will automatically upload your `.uf2` file to the `RPI-RP2` folder

## Creating a New Keyboard

* Navigate to `qmk_firmware/keyboards`
* Create a new folder: `0_se_west`
* Run the following command from QMK MSYS
  ```bash
  qmk new-keyboard
  ```

Enter the following when prompted:

  * **Keyboard Name:** `0_se_west/<your_keyboard>` (choose a keyboard name!)
  * **GitHub Username:** `None`            (not necessary but recommended)
  * **Your Name:** `<your name or alias>`
  * **Default Layout:** `65 (none of the above)`
  * **Development Board:** `n`
  * **Microcontroller:** `21 (rp2040)`
  * <em> Afterwards you should see a new folder at `qmk_firmware/keyboards/0_se_west/<your_keyboard>` </em>
---

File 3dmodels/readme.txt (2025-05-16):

\3dmodels

Overview:
Folder contains all 3D CAD relevant to this project.
When a project revision is released, all relevant models should be archived to the release folder revX.
The FW revision and PCBA revision should always be identical.
If there were no changes to CAD, leave breadcrumbs in the form of readme's.

template_project
├── 3dmodels
│   ├── rev0		(folder)
│   │   ├── pcba_model1.zip
│   │   └── pcba_model2.zip
│   ├── rev1		(folder)
│   │   ├── pcba_model1.zip
│   │   └── pcba_model2.zip
│   ├── rev2		(folder)
│   │   └── same_as_rev1.txt
│   ├── pcba_model1.step
│   └── pcba_model2.step

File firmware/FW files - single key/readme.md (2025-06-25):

# se_west_single_key

se_west_single_key

*A short description of the keyboard/project*

* Keyboard Maintainer: [jsallan](https://github.com/jsallan)
* Hardware Supported: *The PCBs, controllers supported*
* Hardware Availability: *Links to where you can find this hardware*

Make example for this keyboard (after setting up your build environment):

    make se_west_single_key:default

Flashing example for this keyboard:

    make se_west_single_key:default:flash

See the [build environment setup](https://docs.qmk.fm/#/getting_started_build_tools) and the [make instructions](https://docs.qmk.fm/#/getting_started_make_guide) for more information. Brand new to QMK? Start with our [Complete Newbs Guide](https://docs.qmk.fm/#/newbs).

## Bootloader

Enter the bootloader in 3 ways:

* **Bootmagic reset**: Hold down the key at (0,0) in the matrix (usually the top left key or Escape) and plug in the keyboard
* **Physical reset button**: Briefly press the button on the back of the PCB - some may have pads you must short instead
* **Keycode in layout**: Press the key mapped to `QK_BOOT` if it is available

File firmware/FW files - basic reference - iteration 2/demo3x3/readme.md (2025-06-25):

# Overview
This is the final basic macropad code. It supports the 3x3 switch matrix, and the backlight.

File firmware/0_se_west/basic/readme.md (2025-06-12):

# 0_se_west/demo1x3

0_se_west/demo1x3

*Demonstration MVP keyboard for WEST*

* Keyboard Maintainer: [Jesse Farrell](https://github.com/jessefarrell)
* Hardware Supported: Raspberry Pi Pico
* Hardware Availability: RPI store

Make example for this keyboard (after setting up your build environment):

    make 0_se_west/demo1x3:default

Flashing example for this keyboard:

    make 0_se_west/demo1x3:default:flash

See the [build environment setup](https://docs.qmk.fm/#/getting_started_build_tools) and the [make instructions](https://docs.qmk.fm/#/getting_started_make_guide) for more information. Brand new to QMK? Start with our [Complete Newbs Guide](https://docs.qmk.fm/#/newbs).

## Bootloader

Enter the bootloader in 3 ways:

* **Bootmagic reset**: Hold down the key at (0,0) in the matrix (usually the top left key or Escape) and plug in the keyboard
* **Physical reset button**: Briefly press the button on the back of the PCB - some may have pads you must short instead
* **Keycode in layout**: Press the key mapped to `QK_BOOT` if it is available

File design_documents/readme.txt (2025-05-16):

\design_documentation

Overview:
Folder contains all misc. engineering documentation relevant to this project.
None of this data should be revision specific. However, info still needs to be documented thoroughly.

template_project
├── Design_Docs
│   ├── datasheets 		(folder)
│   ├── spice_simulation	(folder)
│   ├── calculations.xlsx
│   ├── checklist.xlsx
│   ├── errata.xlsx
│   └── HAS.docx

Details...
datasheets (folder) 		- Store all datasheet pdf's
spice_simulation (folder) 	- Store ltspice (or other) simulations here.
calculations.xlsx 		- All relevant, none trivial calculations made during design.
HAS.docx 			- Hardware Architecture Specification, final user facing documentation package.
checklist.xlsx 			- checklist used to validate design before release.
errata.xlsx			- Any issues found on a specified HW revision.

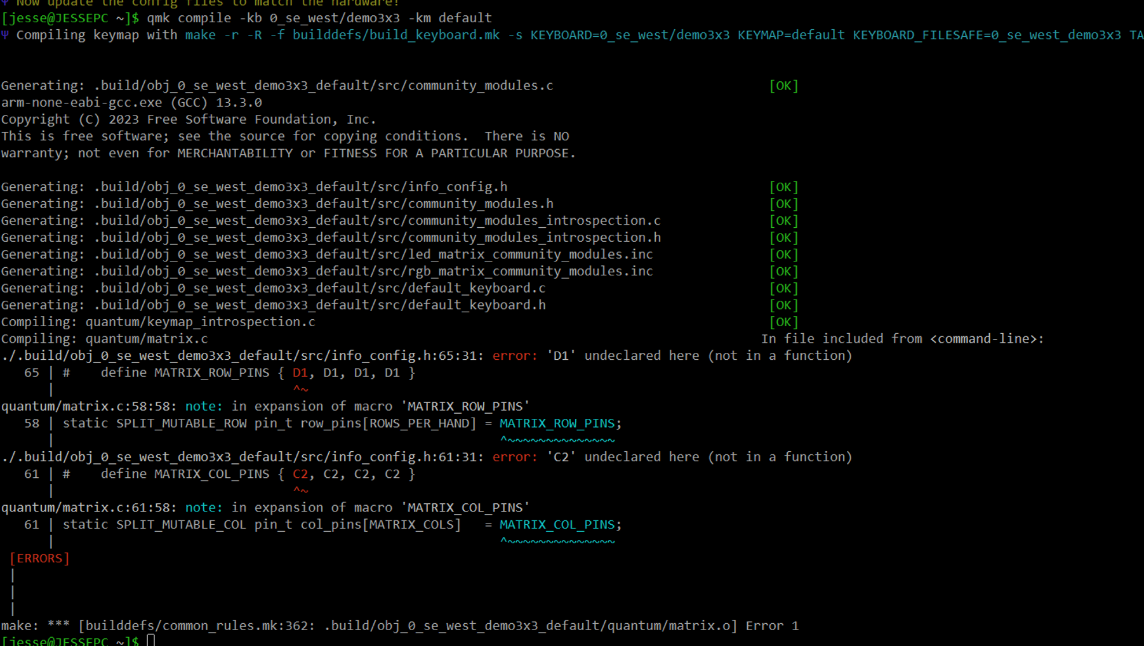
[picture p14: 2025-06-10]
images/compile_fail.png

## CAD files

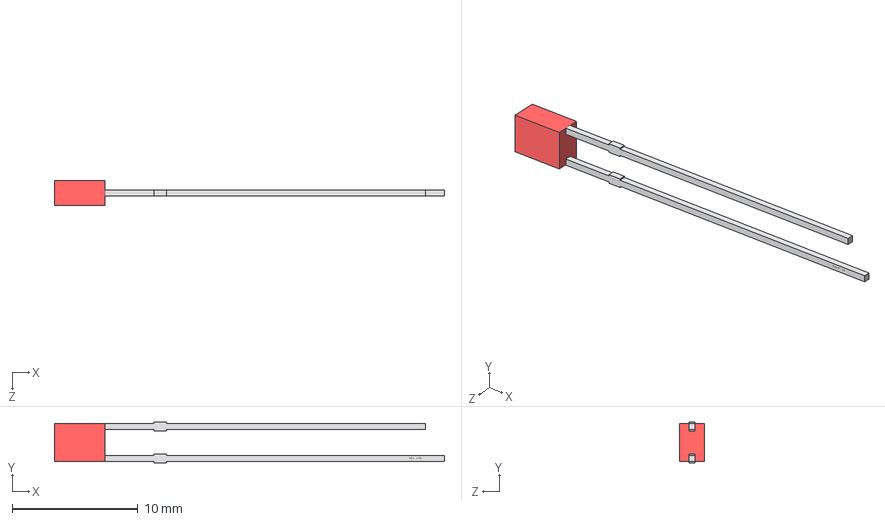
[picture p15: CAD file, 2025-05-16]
3dmodels/Kingbright_WP914x_(Exact).STEP
31.0 x 3.24 x 2.00 mm

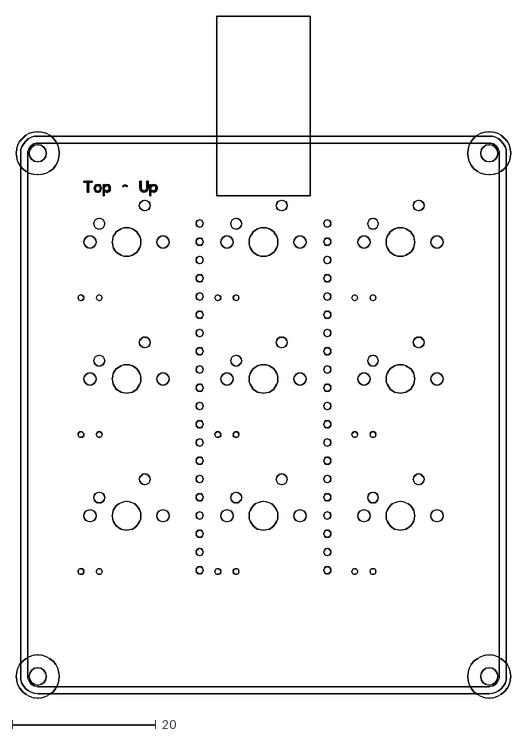
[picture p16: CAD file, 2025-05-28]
design_documents/Basic_PCB_outline.dxf
68.8 x 94.9

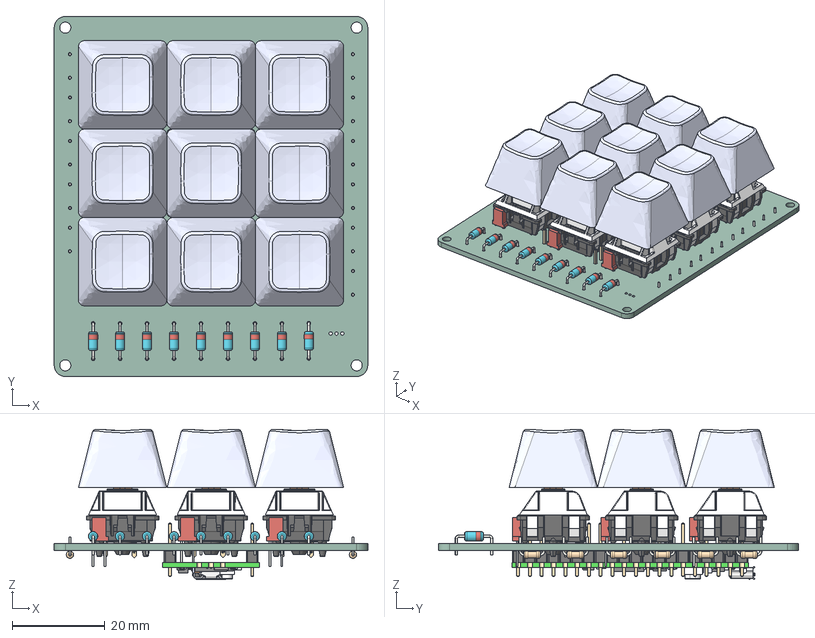
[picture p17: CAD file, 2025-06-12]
mechanical-resources/basic_macropad.step
67.6 x 77.6 x 32.4 mm
LED_Rectangular_W3.0mm_H2.0mm x 9
SW_Cherry_MX_PCB x 9
Keycap x 9
D_DO-35_SOD27_P7.62mm_Horizontal x 9
R_Axial_DIN0204_L3.6mm_D1.6mm_P5.08mm_Horizontal x 11
PCB, Raspberry Pi Pico-R3
MicroUSB Port, Raspberry Pi Pico-R3
RP2040 Microcontroller, Raspberry Pi Pico-R3
SW1, Tact Switch, Raspberry Pi Pico-R3
D1, Diode, Schottky, Raspberry Pi Pico-R3
D2, QSME-C194, LED, Raspberry Pi Pico-R3
L1, Inductor, Raspberry Pi Pico-R3
U2, RT6150B-33GQW, Buck Boost Converter, Raspberry Pi Pico-R3
U3, W25Q16JVUXIQ, Serial NOR Flash 16 Mbit, Raspberry Pi Pico-R3
Q1, MOSFET, DMG1012T, Raspberry Pi Pico-R3
X1, X12M000000S096, 12 Mhz Crystal Resonator, Raspberry Pi Pico-R3
SMD Resistor, Configurable, Raspberry Pi Pico-R3_R1
SMD Resistor, Configurable, Raspberry Pi Pico-R3_R2
SMD Resistor, Configurable, Raspberry Pi Pico-R3_R3
SMD Resistor, Configurable, Raspberry Pi Pico-R3_R4
SMD Resistor, Configurable, Raspberry Pi Pico-R3_R5
SMD Resistor, Configurable, Raspberry Pi Pico-R3_R6
SMD Resistor, Configurable, Raspberry Pi Pico-R3_R7
SMD Resistor, Configurable, Raspberry Pi Pico-R3_R8
SMD Resistor, Configurable, Raspberry Pi Pico-R3_R9
SMD Resistor, Configurable, Raspberry Pi Pico-R3_R10
SMD Resistor, Configurable, Raspberry Pi Pico-R3_R11
SMD Resistor, Configurable, Raspberry Pi Pico-R3_R12
SMD Resistor, Configurable, Raspberry Pi Pico-R3_R13
SMD Resistor, Configurable, Raspberry Pi Pico-R3_R14
SMD Resistor, Configurable, Raspberry Pi Pico-R3_R15
SMD Capacitor, Configurable, Raspberry Pi Pico-R3_C1
SMD Capacitor, Configurable, Raspberry Pi Pico-R3_C2
SMD Capacitor, Configurable, Raspberry Pi Pico-R3_C3
SMD Capacitor, Configurable, Raspberry Pi Pico-R3_C4
SMD Capacitor, Configurable, Raspberry Pi Pico-R3_C5
SMD Capacitor, Configurable, Raspberry Pi Pico-R3_C6
SMD Capacitor, Configurable, Raspberry Pi Pico-R3_C7
SMD Capacitor, Configurable, Raspberry Pi Pico-R3_C8
SMD Capacitor, Configurable, Raspberry Pi Pico-R3_C9
SMD Capacitor, Configurable, Raspberry Pi Pico-R3_C10
SMD Capacitor, Configurable, Raspberry Pi Pico-R3_C11
SMD Capacitor, Configurable, Raspberry Pi Pico-R3_C12
SMD Capacitor, Configurable, Raspberry Pi Pico-R3_C13
SMD Capacitor, Configurable, Raspberry Pi Pico-R3_C14
SMD Capacitor, Configurable, Raspberry Pi Pico-R3_C15
SMD Capacitor, Configurable, Raspberry Pi Pico-R3_C16
SMD Capacitor, Configurable, Raspberry Pi Pico-R3_C17
SMD Capacitor, Configurable, Raspberry Pi Pico-R3_C18
PinHeader_1x20_P2.54mm_Vertical x 2
west_workshop_2025_PCB

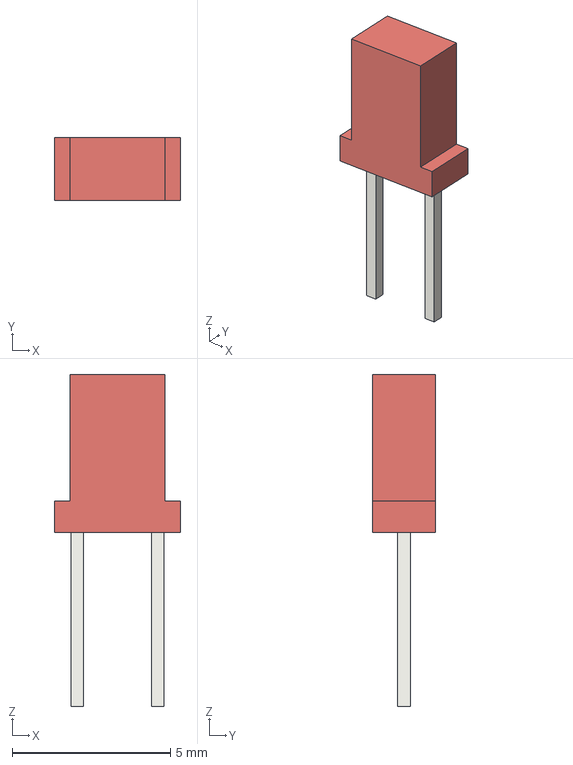
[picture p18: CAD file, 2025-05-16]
3dmodels/Kingbright_WP914x_(Similar).step
4.00 x 2.00 x 10.5 mm

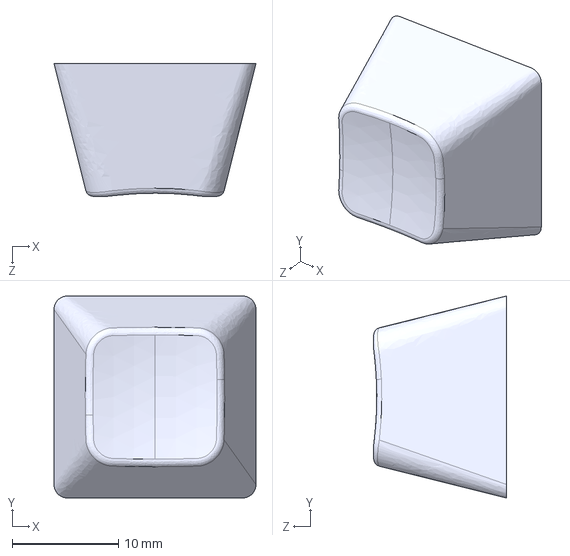
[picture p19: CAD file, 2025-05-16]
3dmodels/Keycap.STEP
19.1 x 19.1 x 12.6 mm

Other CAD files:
mechanical-resources/Advanced-keypad-case-MK2.f3d

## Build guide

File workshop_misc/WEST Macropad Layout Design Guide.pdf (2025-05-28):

### Schneider Electric

# Macropad

### WEST Project Victoria, BC, Canada

### Layout Design Asil Helali Summer 2025

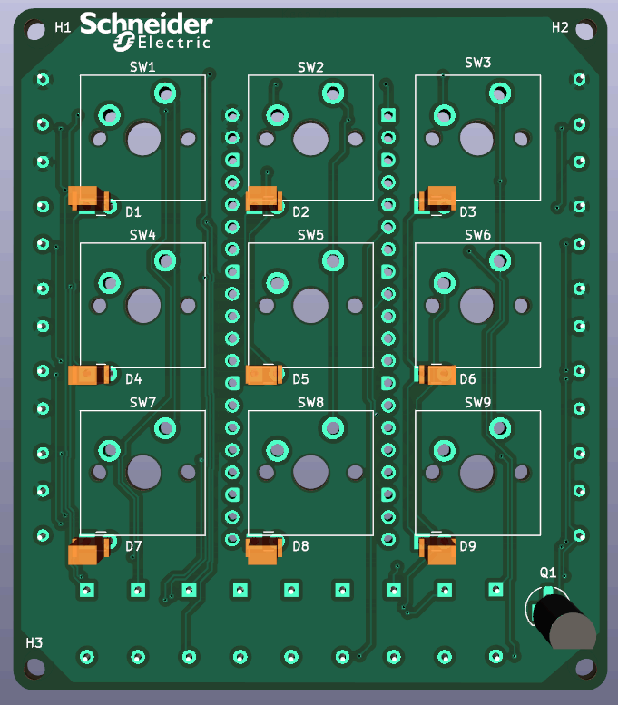
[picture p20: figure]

## Table of Contents

List of Figures | 2
1.0 Board Setup | 3
1.1 Annotate the Schematic | 3
1.2 Footprint Library Sync | 4
1.3 PCB Stackup | 5
1.4 Constraints Manager | 7
1.5 Uploading the Mechanical Outline | 8
1.6 Schematic to PCB Sync | 9
2.0 Board Design | 9
2.1 Creating the Board Outline | 9
2.2 Creating Copper Planes and Assigning Nets | 11
2.3 Aligning Components | 15
2.3.1 Placing and Aligning Components | 15
The Switches: | 15
The Microcontroller: | 17
2.3.2 Editing Footprints | 17
2.3.3 Trace Width | 19
2.3.2 Vias | 20
2.3.3 Copper Flow and Islands | 21
2.3.4 Design Rule Checker (DRC) | 23
2.4 Silk Screen | 23
2.4.1 Adding a Logo (optional) | 24
3.0 Exporting Design | 25
3.1 Drawing Sheet Table | 25
3.2 Gerber Files | 25
3.3 Exporting Mechanical STEP File (optional) | 26
3.4 Final Results | 27
4.0 Check-List | 28
5.0 Resources | 29

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
## 1.0 Board Setup

This section of the document is going to walk you through how to setup the KiCAD tool to start your layout design.

### 1.1 Annotate the Schematic

Before starting the layout design, we must ensure that all components are annotated on the schematic. This is done to allow the tool to import successfully without any errors from schematic to layout. It provides proper synchronization and its good practice for organization.

Open the Schematic Editor → Tools → Annotate the Schematic → Reset Existing Annotations → Annotate.

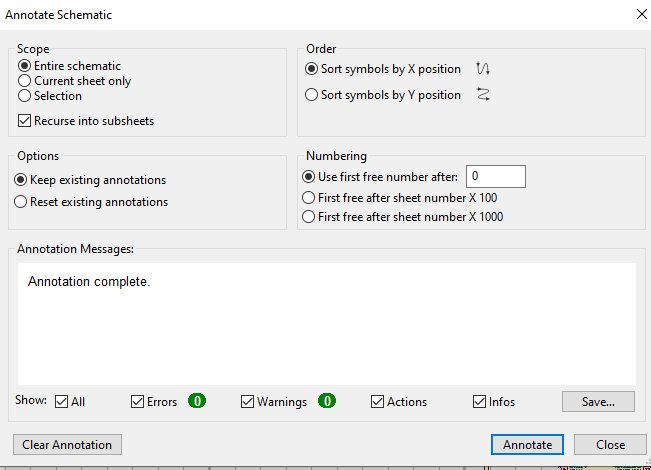
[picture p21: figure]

Figure 1: Annotate Schematic

### 1.2 Footprint Library Sync

KiCad has a basic footprint library that is automatically installed, however for more specific footprints (eg. switches) extra footprint plugins need to be downloaded. In the main KiCAD window go to Tools → Plugin and Content Manager, then install the Keyswitch Kicad Library.

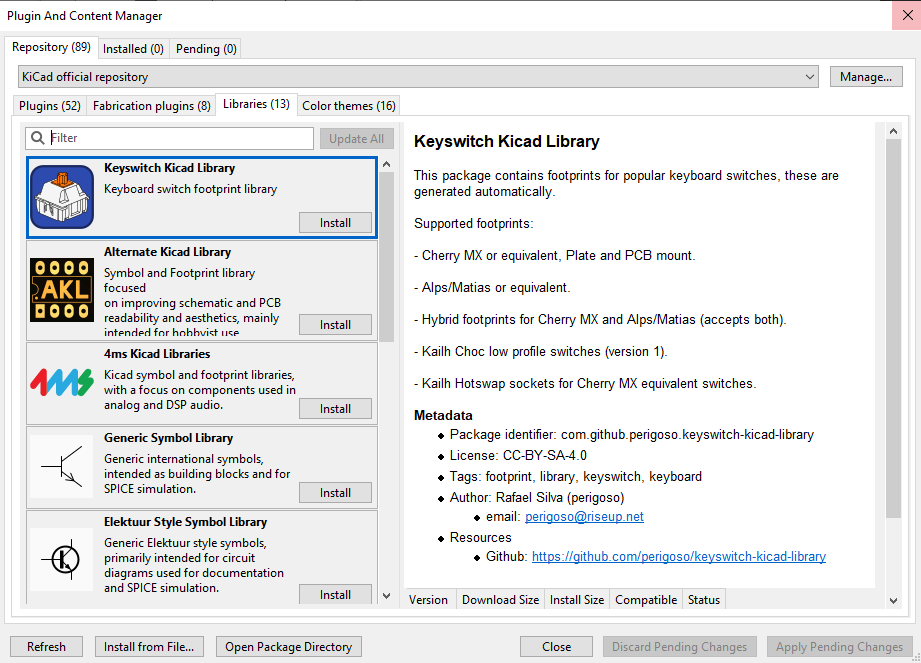
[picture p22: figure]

Figure 2: Downloading Footprint Library

Note: This does not need to be done for this project, all parts were already included in advance.

### 1.3 PCB Stackup

The stackup of a PCB refers to the specific layering of conductive (copper) and insulating (dielectric) materials that make up a printed circuit board. The stackup defines how many layers the PCB has, the thickness of each layer, the material and their order. For this project, we will be making a 2 copper layer board. To look at the stack up go to File → Board Setup→ Physical Stackup. From there you can choose the amount of layers you want your board to be.

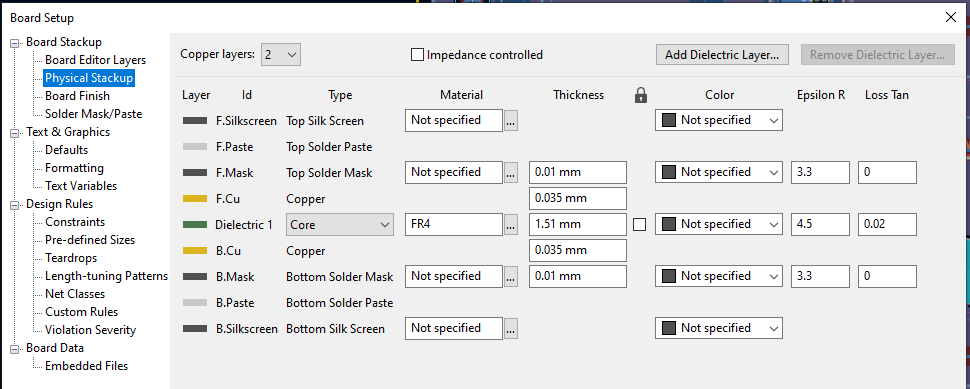
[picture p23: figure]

Figure 3: Board Stackup

In the stackup, there is a total of 9 layers for a 2 copper layer board:
- Silkscreen: The top most surface layer, non conductive, it's the “writing” on the board, which provides essential information like component identifiers, polarity, test points, specific instructions and logos.
- Solder Paste: This layer defines the areas on the board where solder paste (a material made up of powdered metal solder and flux medium) is applied on the PCB for surface mount components.
- Solder Mask: This layer is a protective polymer coating that insulates copper traces and prevents solder bridges between closely placed pads by covering all areas except for the solderable pads and holes.
- Front Copper: This is a copper plane on the board, it’s used to form conductive pathways, pads and lands for electrical connections to components. It provides electrical flow, signal transmission, power distribution and heat dissipation.

- Dielectric Core: This is a solid non-conductive layer that provides mechanical stability and electrical insulations between copper layers. The copper layer is laminated on one (or both sides) of this core. It prevents electrical shorts between conductive layers.
- Back Copper: Same as Front Copper layer, on the other side of the dielectric core.
- Prepreg: Shown in Figure 3, this layer is made up of fiberglass impregnated with partially cured resin. It acts as an adhesive to bond together the copper cores as well as insulation between the layers. It provides mechanical strength, electric isolation.

Note: F and B refer to Front and Back.

In the Board Setup window, you can specify the material for each layer as well as the thickness. The core material that we will be using for this project is FR4 ( flame retardant 4) which is a type of epoxy resin that self-extinguishes if ignited which enhances safety for the PCB.

The layer thickness is standardized. The most common PCB thickness is 1.57mm (62mils). When choosing the stackup thickness, keep in mind the current, environmental factors and space constraints, impedance and cost constraints.

Figure 4: Exploded PCB Stackup View

### 1.4 Constraints Manager

The first thing you have to do is set up your board constraints. These are the manufacturing limitations that make sure the boards are working as intended. They prevent issues like soldering defects, assembly problems and shorts.

These constraints are taken directly from the JLC website which is the manufacturer that we will be using for this project. PCB Manufacturing & Assembly Capabilities - JLCPCB (https://jlcpcb.com/capabilities/Capabilities)

To edit your constraints go to File → Board Setup → Constraints. Copy the values from the figure below.

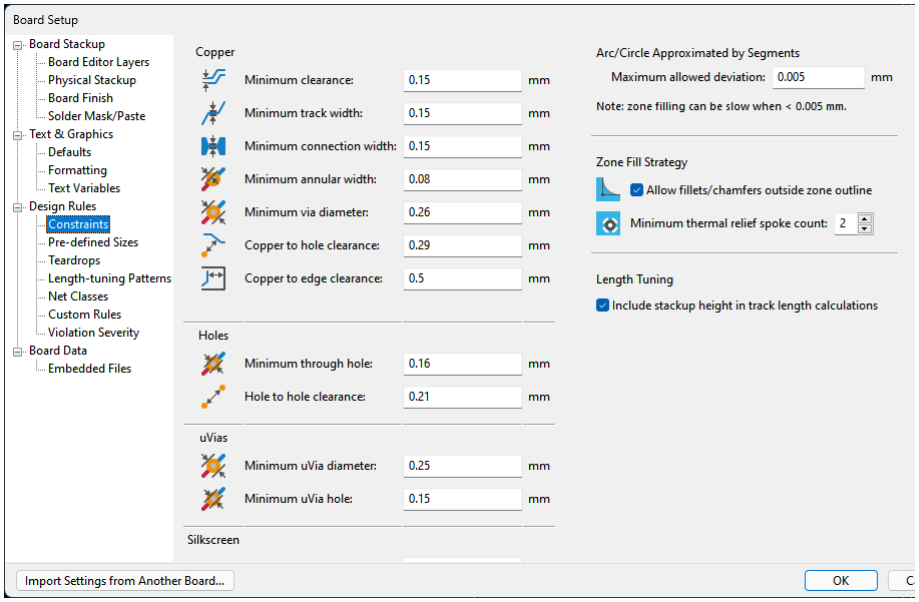
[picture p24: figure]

Figure 5: Constraint Values

### 1.5 Uploading the Mechanical Outline

Mechanical outlines are provided to give guidance and show the boundaries of the enclosure. They provide insight on the height restrictions, location of switches and where the screw holes are. They come in the form of a .DXF file, which will be provided.

To import the outline go to File → Import → Graphics.

When the “Import Vector Graphics File” window appears, locate and upload the .DXF file. Make sure to change the “DXF default units” to millimeters and double check the layer selected is “User.Drawings”. Click “OK” and place the outline within the sheet.

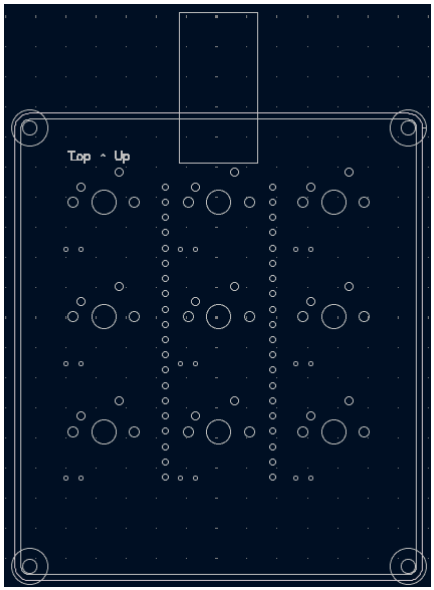
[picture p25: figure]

Figure 6: Mechanical Outline

### 1.6 Schematic to PCB Sync

Once the libraries are all installed, we can now upload all components from the schematic to the PCB. In the PCB Editor window, go to Tools → Update PCB from Schematic. Make sure there are no Errors or Warnings and then click “Update PCB” and place all the components to the side.

Figure 7: Footprints Placed

## 2.0 Board Design

This section of the document is going to walk you through how to start and complete your layout design.

### 2.1 Creating the Board Outline

In this section we will be creating the board outline. Right click on the outer mechanical drawing boundary and go to properties. In the “Segment Properties” window, change the layer to “Edge.Cuts”. Each segment on the outline will need to be done individually.

Note: If you are unable to select each segment individually, you might need to “ungroup” the section by right clicking → Grouping → Ungroup Items.

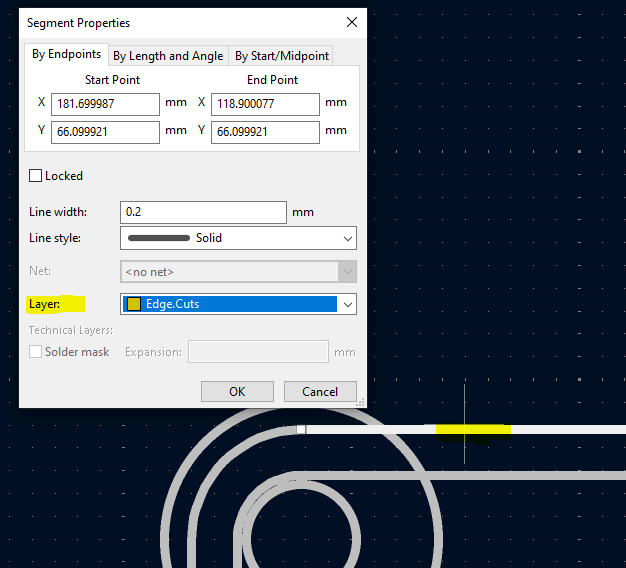
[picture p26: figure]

Figure 8: Segment Properties Example

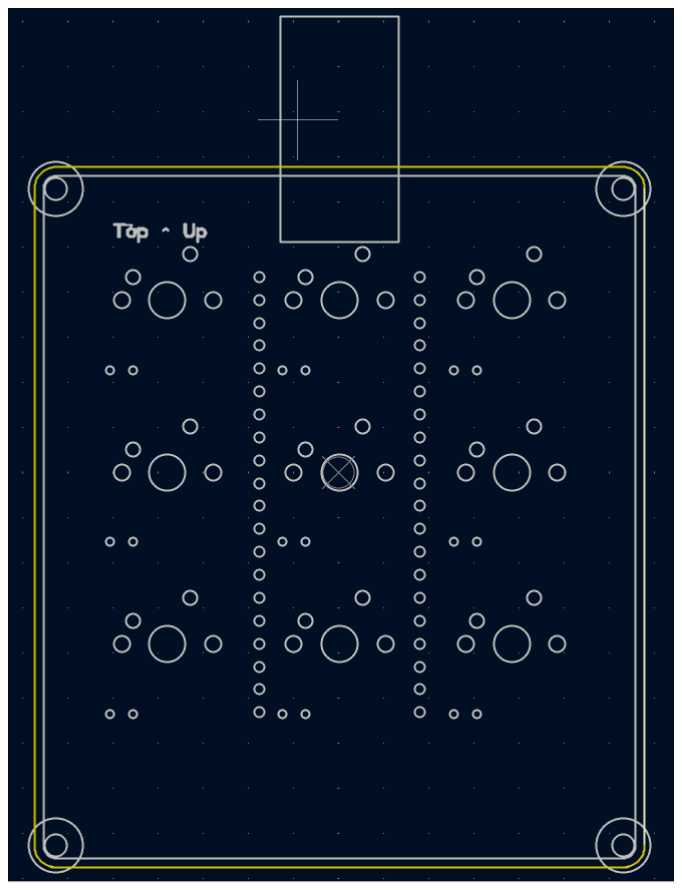
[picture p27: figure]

Figure 9: Edge.Cuts Outline Completed

Once the board outline is completed, make sure to lock both the “Edge.Cuts” and “User.Drawings” layers by right clicking → Locking → Lock. This ensures that the outlines do not move. If you want to edit / unlock a locked item, make sure the “Locked Items” button is selected in the “Selection Filter” tab on the bottom right section.

Figure 10: Locked Layers Example

### 2.2 Creating Copper Planes and Assigning Nets

This is a 2- layer board so we will need to create 2 copper planes. The top plane will be the power plane, which is +5V and the bottom plane will be ground. Planes are mainly used to evenly distribute voltage across the PCB and to provide a stable connection to all components.

The copper plane provides an area for electrical signals to flow between components. This is done by forming traces and pads and connections on the copper plane.

All conductive planes will be at least 0.5mm less than the board outline. This is done to prevent any accidental copper exposure that could cause shorts.

The inner mechanical outline is about 0.8mm from the board outline (this can be checked using the measuring tool) and it is where we will place the copper planes.

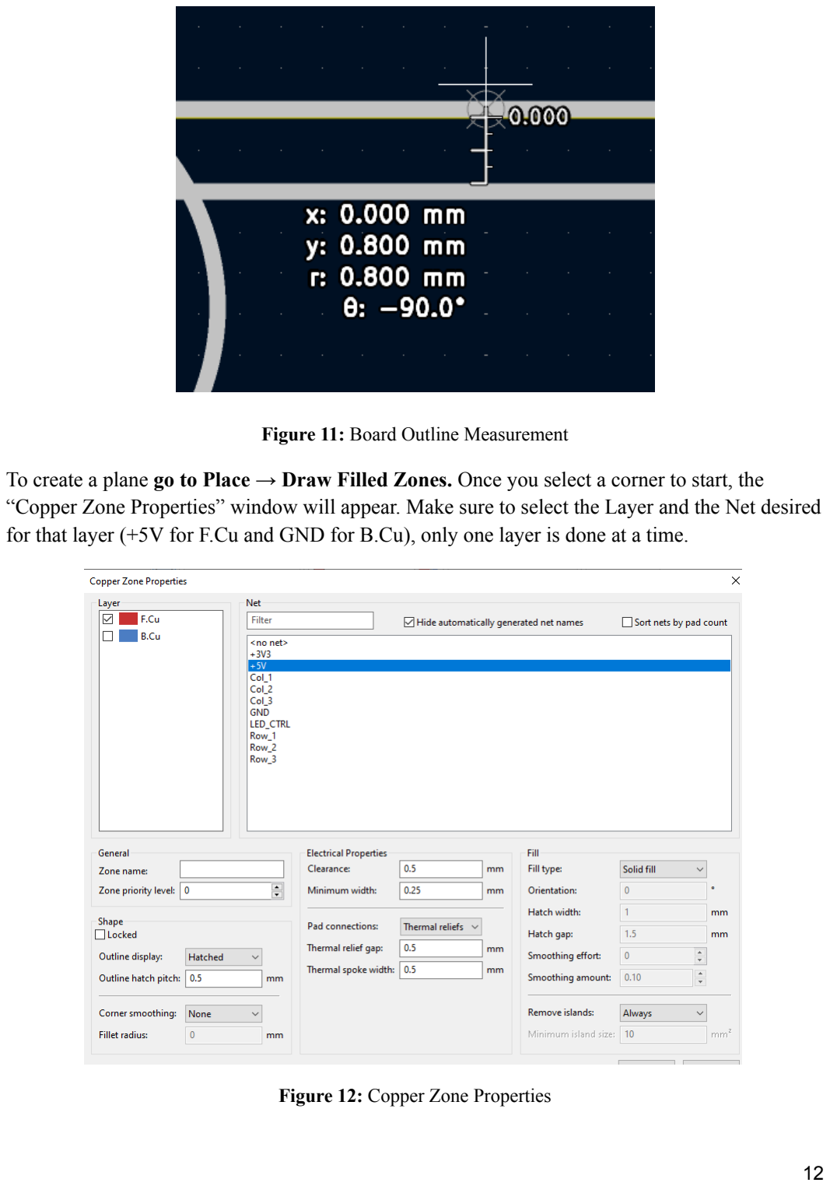
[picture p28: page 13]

Figure 11: Board Outline Measurement

To create a plane go to Place → Draw Filled Zones. Once you select a corner to start, the “Copper Zone Properties” window will appear. Make sure to select the Layer and the Net desired for that layer (+5V for F.Cu and GND for B.Cu), only one layer is done at a time.

Figure 12: Copper Zone Properties

Note: To prevent any conductive exposure to the drill holes, make sure to not include the drill holes within the copper section. See figure below for an example.

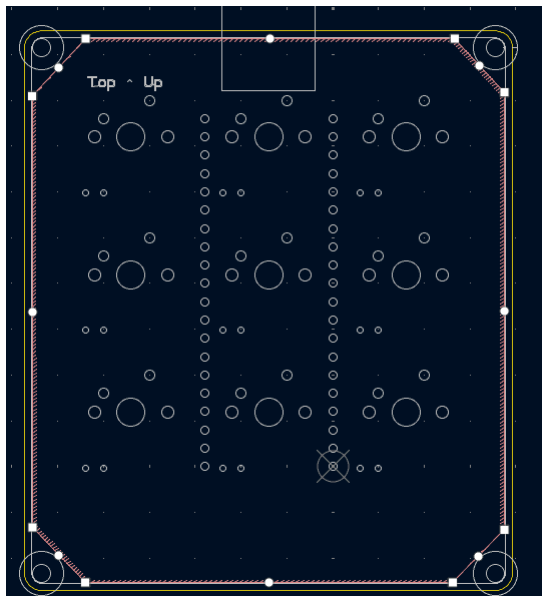
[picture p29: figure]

Figure 13: Copper Zone

Once the outline is complete, you can fill the copper zone by going to Edit→ Fill All Zones or by pressing “B”.

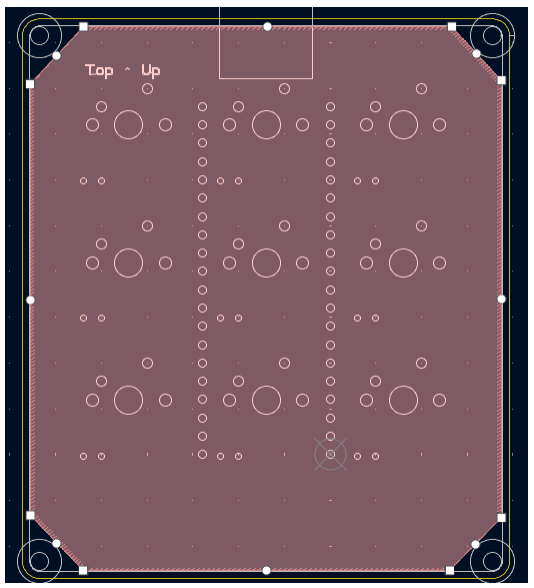
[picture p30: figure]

Figure 14: Front Filled Copper Zone

To create the remaining layer, right click on an already completed plane → Zone → Duplicate Zone onto Layer and then select the correct settings in the “Copper Zone Properties” window. Once that is complete you will have to fill copper zones again by pressing the “B” key.

Figure 15: Back Filled Copper Zone

Double check that both layers have a copper outline by turning off one layer at a time from the “Appearance” panel on the right hand side.

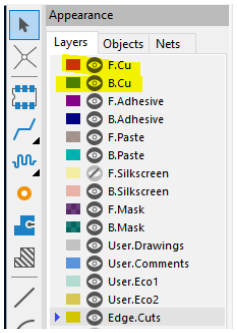
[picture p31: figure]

Figure 16: Appearance Panel

### 2.3 Aligning Components

In this section you will be learning how to place and align components on both sides of the board.

2.3.1 Placing and Aligning Components
Components can be placed anywhere on the board with respect to the mechanical outline and the copper boundaries. Since all components that are being used in the project are through hole components, you need to ensure that no two components overlap if one is placed on the bottom of the board and the other is placed on the top. The mechanical outline provides boundaries for where some components must be placed so that it can fit within the mechanical enclosure. These components are the drill holes for the screws, the switches and the microcontroller.

When placing components, it is easier if you start with the components that have mechanical constraints. In this project’s case, that would be the switches and the microcontroller.

The Switches:
The switches are going to be placed on the top side of the board. Start by placing the grid origin in the middle of the switch, this helps with placing the component in the correct position to align properly with the mechanical outline. Then drag and drop the component and place it on top of the mechanical outline. Place the grid origin by going to Place → Grid Origin.

Note: You can toggle between turning on and off the ratsnest to have a clearer view of your board. A ratsnest are the unrouted wires connecting components before routing. To toggle ratsnest, go to the Appearance tab on the right hand side → Objects → Ratsnets.

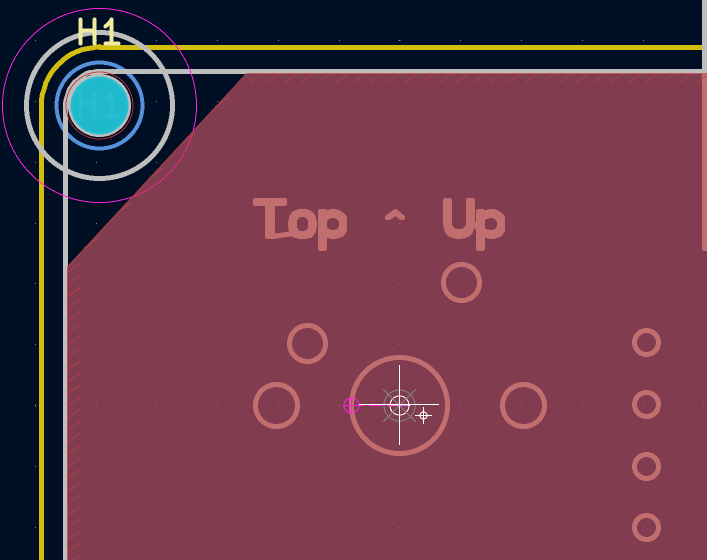
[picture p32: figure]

Figure 17: Grid Origin Placed in Switch

To make moving the component smoother, you can click on the left Ctrl while you drag the component. You can also change the grid size for more precise movement. Change the grid size by right clicking anywhere on the sheet → Grid.

Figure 18: Switch Placed

Once the rest of the switches are placed, you can align the components to each other to ensure they are symmetrical. Vertical and horizontal components must be aligned separately. To align components, select all the components in a row → right click on the component you want the rest to be aligned to → Align/Distribute → Align to Vertical Centre. The same process is done for the vertical columns but the alignment option used will be different.

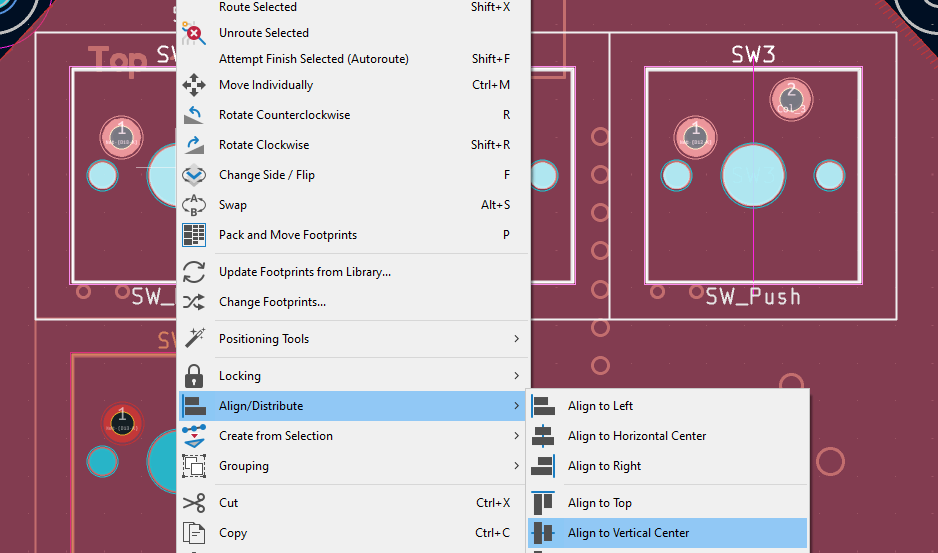
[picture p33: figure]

Figure 19: Aligning Switches

The Microcontroller:
The microcontroller will be placed on the bottom side of the board. To change the layer of a component, right click on the component → Change Side / Flip.

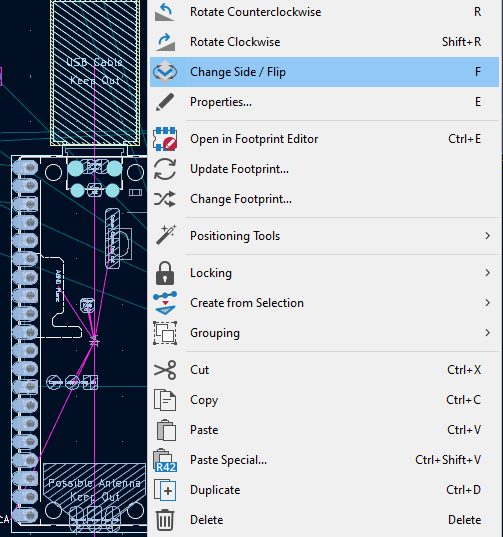
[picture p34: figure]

Figure 20: Changing Component Layer

Place the microcontroller on the mechanical outline using the same alignment steps as above.

Note: Once all the components are placed, make sure to refill all copper zones by clicking “B”. This will re-flow all the copper and take out the copper under any holes / traces.

2.3.2 Editing Footprints
For the purpose of this exercise, an example of editing the microcontroller footprint will be shown but note that the footprint does not need to be edited, it was already done in advance.

The microcontroller has multiple different keep-outs that will not be affecting the design and therefore need to be deleted. Delete the “Possible Antenna” keep out boundary, we will not be using an antenna for this design and it will provide more copper flow for board as well as extra space for tracing. We will also be deleting the “Exposed Copper Keep Out” boundary. This is because the microcontroller will not be touching the PCB, it will be lifted off using headers and therefore won’t affect the design.

To edit the footprint, right click on the component → Properties → Edit Footprint → Select the keep out boundary and delete and save.

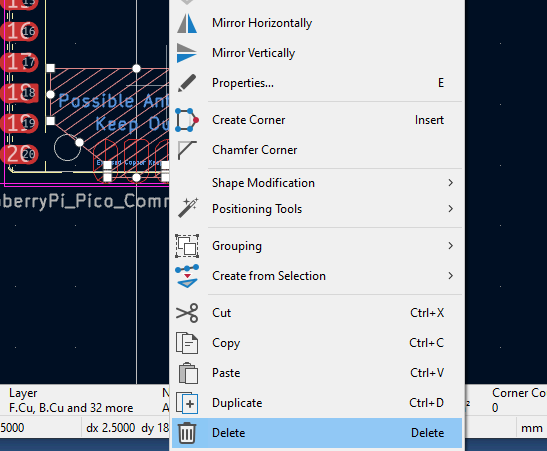
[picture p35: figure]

Figure 21: Editing Footprint

The microcontroller footprint after edits should look like the Figure 21 below.

Figure 22: Final Microcontroller Footprint

2.3.3 Trace Width
Once all the components are placed, the next step is to connect the components together. The components are routed together using traces.

The trace width can be determined by the current the trace must carry, the temperature rise as well as the copper thickness. We also must keep in mind the minimum trace width that is set by the manufacturer.

For low-current signal traces, the typical trace width ranges from 0.007-0.012 inches. Power and ground traces need to be wider to safely carry higher current without overheating and causing damage. Wider traces also reduce voltage drop making sure the components get their required voltage levels. The power and ground trace widths typically range from 0.015 inches and up, larger currents require 0.030 inches and up.

This is a low-current project, therefore for the signal trace width we will be using 0.007874 inches (0.2mm) and for the ground and power trace width we will use 0.0197 inches (0.5mm).

You can pre-set the trace width by going to File → Board Setup → Design Rules → Pre-defined sizes.

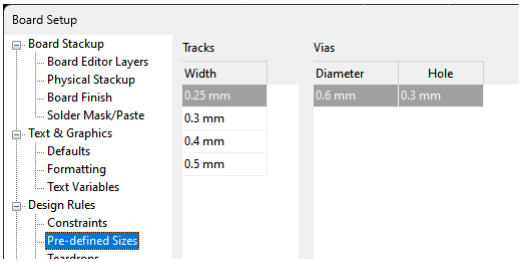
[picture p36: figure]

Figure 23: Defining Trace Width and Via Size

To place a trace go to Route → Route Single Track.

Switch the trace size using the “Track” drop down menu on the top panel.

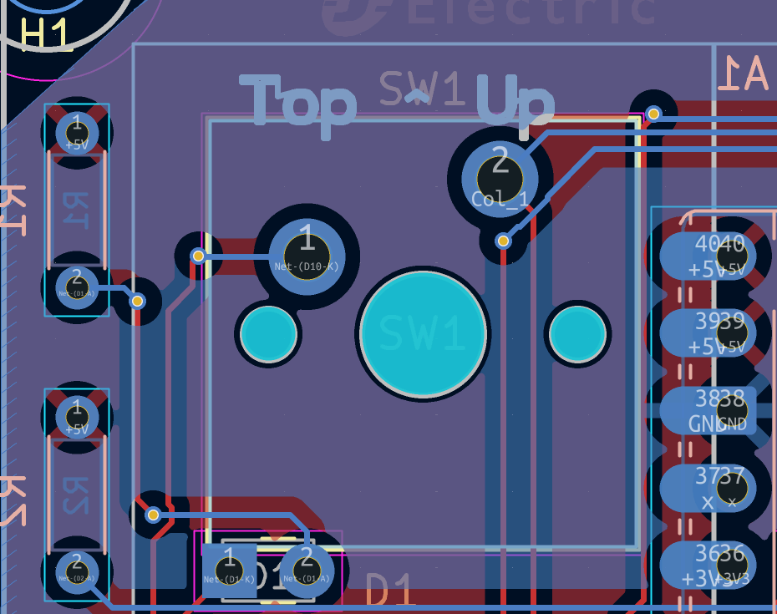
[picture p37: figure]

Figure 24: Example of Traces on the PCB

When placing a trace, you can toggle between layers as mentioned in the sections above. Typically with two layer boards, one layer would be dedicated to horizontal trace routes and the other would be for vertical routing.

Note: There is a calculator tool on KiCAD that could be used to calculate trace and via sizes!

2.3.2 Vias
Vias are small plated holes in a PCB that electrically connect different layers of the board together. This allows power and signals to pass vertically through the board. Traces connect to each other on different layers of the board through vias.

Vias are particularly useful for providing power distribution, space optimization, electrical connectivity, signal integrity (they minimize noise and signal distortion). The standard via size that will be used for this project is 0.6mm diameter and 0.3mm hole. Preset the via size going to File → Board Setup → Design Rules → Pre-defined sizes.

To continue a track from one layer of the board to another, add a via by going to Place → Place Via.

Figure 25: Example of Vias on the PCB

2.3.3 Copper Flow and Islands
Copper flow is one of the most important aspects of a layout design.The goal is to have a well-distributed and continuous copper plane to provide reliable signal transmission. An uneven copper flow could cause inaccuracies and signal degradation.

Copper islands are isolated areas of copper on the PCB that are not electrically connected to any net or trace. They unintentionally formed while routing and placing components that leave small, disconnected patches of copper. We need to make sure that they are not on the PCB by shifting routing / components to avoid them. Figure 25 is an example of a copper island and Figure 26 is an example of a good copper flow.

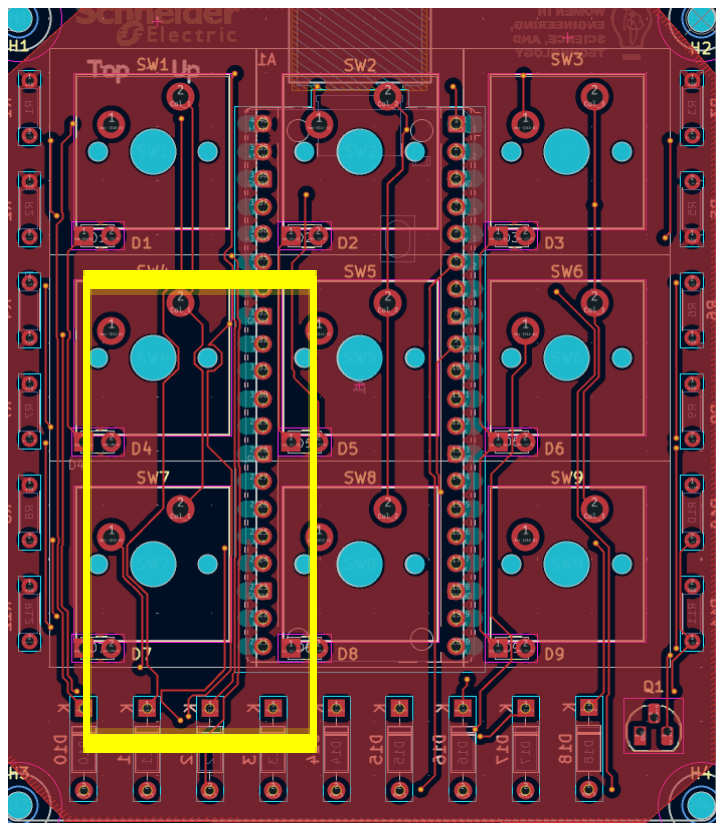
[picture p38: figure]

Figure 26: Example of a Copper Island

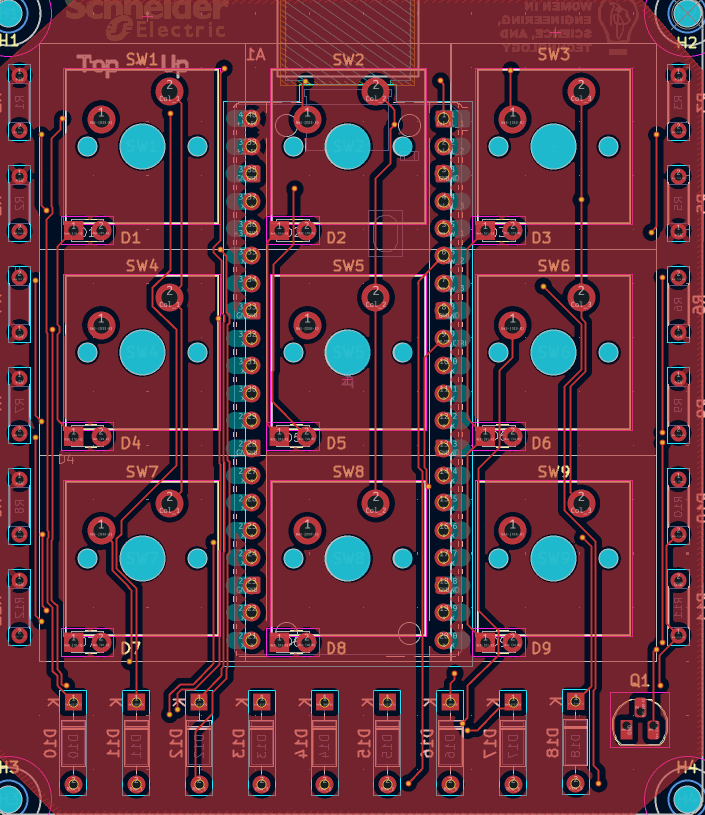
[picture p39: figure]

Figure 27: Example of Good Copper Flow

2.3.4 Design Rule Checker (DRC)
The design rule checker identifies any errors that are affecting the design. Common errors include components not connected, components boundaries are overlapping, components placed in a “keep out” zone etc. Some errors are expected and don’t need to be addressed as long as they are understood and justified. For example, in this design we intentionally placed the LEDs boundaries overlapping with the switch footprint to provide better backlight.

To check DRC’s go to Inspect → Design Rule Checker.

Figure 28: DRC Errors and Warnings

The Error “Courtyards overlap” and Warning “Silkscreen clipped by soldermask” that are referring to the switches and LEDs are intentional and will not affect the design.

### 2.4 Silk Screen

The silkscreen is the topmost layer of printed text, symbols, logos and graphics on the board’s surface. It’s used to indicate the components reference designators and polarity and it can provide warnings or have special instructions as well as providing relevant information about the board.

2.4.1 Adding a Logo (optional)
To add a logo onto your design, go to the main KiCad window and click on Image Converter → Load Source Image → Select Image → Output Format → Footprint → Edit size is desired → Export to File – Save.

Go back to layout design and go to Tools → Footprint Editor → File → Import → Footprint → Select Logo → Save into Footprint Library.

Exit out of the Footprint Editor and go back to layout design and go to Place → Place Footprints, locate the logo and place it on the board. Ensure that it is on the Silkscreen layer.

Note: Make sure that the logo chosen is a transparent image and save as a PNG.

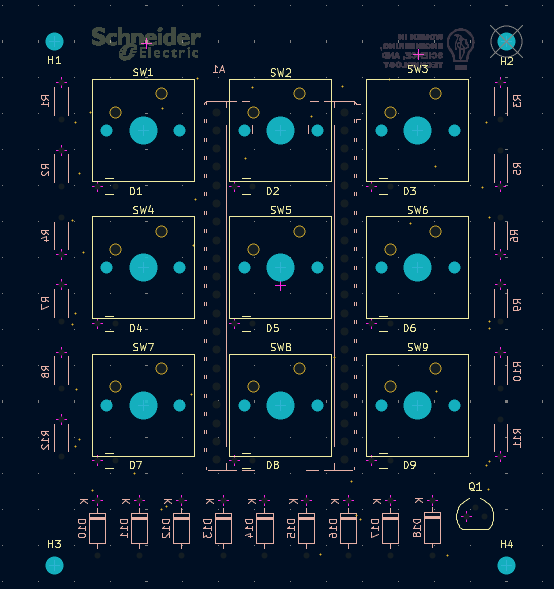
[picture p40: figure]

Figure 29: Top and Bottom Silkscreen Layers

## 3.0 Exporting Design

### 3.1 Drawing Sheet Table

The drawing sheet table is where you can edit the title block / information table on the bottom right side of the layout design. In that block, you can add what revision the board is in, the date, name as well as the designer. To edit the drawing sheet, go to File → Page Settings.

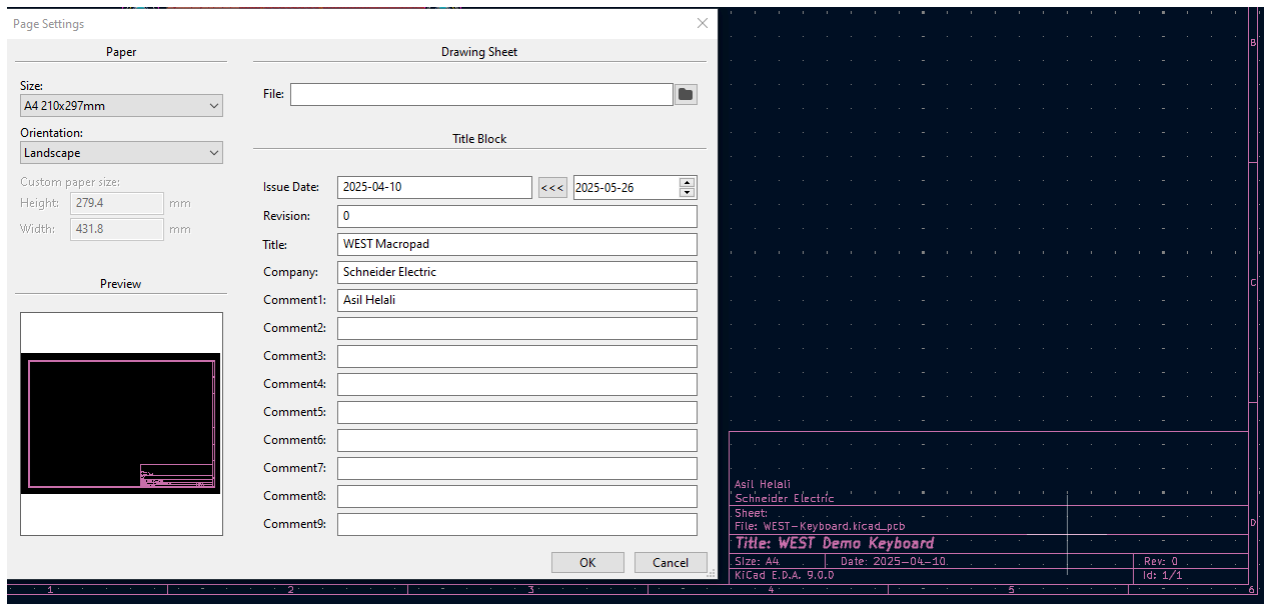
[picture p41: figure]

Figure 30: Page Information Settings

### 3.2 Gerber Files

Gerber files give you detailed information about each layer of a PCB. Each gerber file corresponds to one specific layer such as copper layers, solder paste, silkscreen, it also generates the drill hole information. It describes the exact sizes and shapes of all elements on all layers. These files are what each manufacturer uses when ordering a PCB board.

To export Gerber files go to File → Plot → Plot Format → Gerber → Chose an Output directory

Make sure the following layers are selected:
- F.Cu
- B.Cu
- F.Paste
- B.Paste

- F.Silkscreen
- B.Silkscreen
- F.Mask
- B.Mask
- Edge.Cuts

Click on “Generate Drill Files” once that is complete, click on “Plot”

Double check the gerber files by going to the KiCad window → Gerber Viewer → File → Open Gerber Plot Files and selecting the files to view.

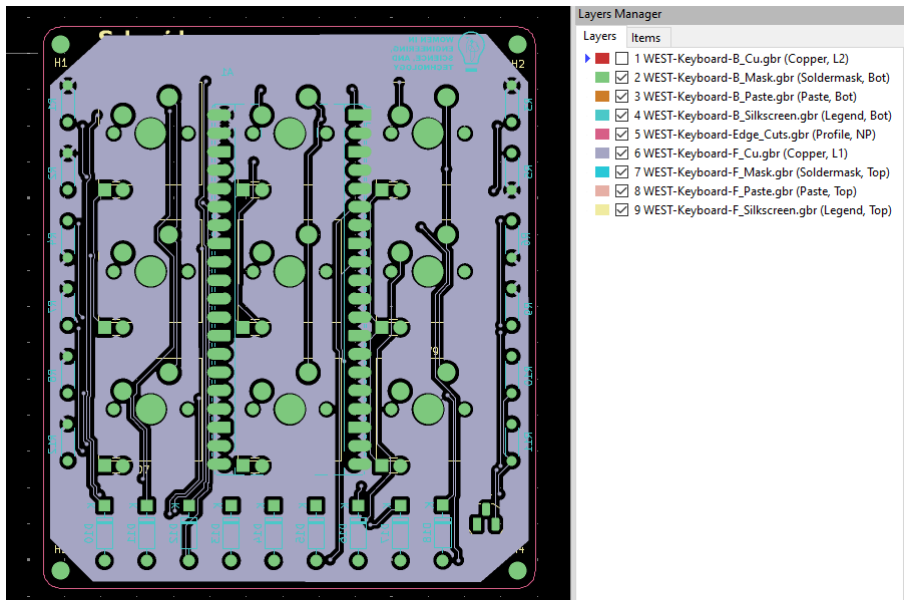
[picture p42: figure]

Figure 31: Gerber Viewer

### 3.3 Exporting Mechanical STEP File (optional)

.STEP (Standard for the Exchange of Product Data) are files that contain the 3D model of the PCB. They are mostly used for mechanical design purposes. This file can be uploaded to Fusion 360 and the enclosure can be built around it.

To export a .STEP file go to File → Export → STEP.

Note: To view the 3D model, go to PCB Editor Window → View → 3D Viewer.

### 3.4 Final Results

Figure 32: Final PCB Front Side

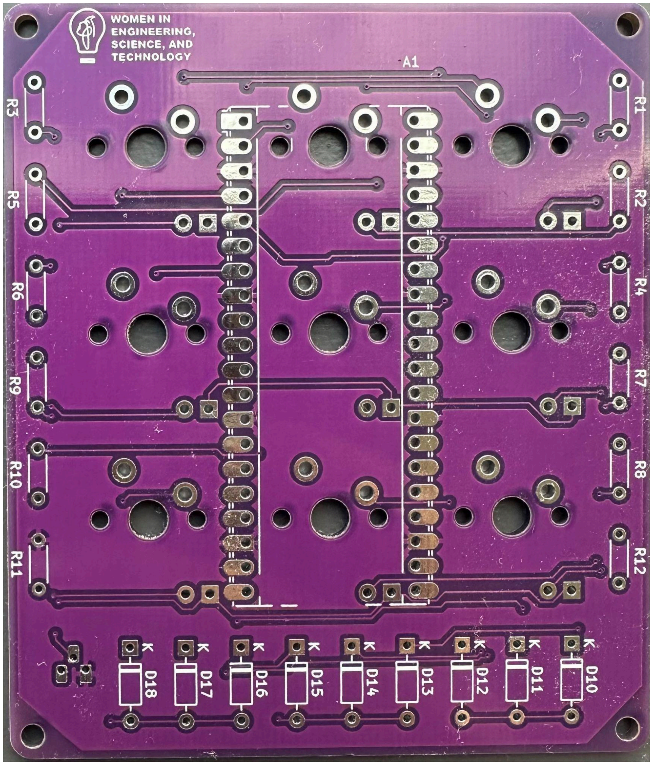
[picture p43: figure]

Figure 33: Final PCB Back Side

## 4.0 Check-List

Annotate the schematic
Board constraints are set
Mechanical outline is uploaded Footprint library is updated (not needed) Board outline
Ground copper plane
Power (+5V) copper plane
Are the copper planes at least 0.5mm away from the board outline? Copper plane is NOT overlapping with the screw holes Components are on the board
Components are exactly aligned with the mechanical outline
Are all components routed?
Do the power and ground pins on components flow nicely on the plane? Are there any copper islands?
Is there good copper flow?
No unexpected errors when running the DRC
If there are DRC’s, are they justified?
Are all reference designators clearly placed on the silkscreen Did you add a logo? (optional)
Gerber files exported
.STEP file exported (optional)

## 5.0 Resources

- KiCad 9.0 Layout Reference Manual: https://docs.kicad.org/9.0/en/pcbnew/pcbnew.html
- “An Intro to KiCad” Tutorial videos: https://www.youtube.com/watch?v=4Gtd7xY6zS4&list=PL3bNyZYHcRSUhUXUt51W6nKvxx2ORvUQB&index=3 (https://www.youtube.com/watch?v=4Gtd7xY6zS4&list=PL3bNyZYHcRSUhUXUt51W6nKvxx2ORvUQB&index=3)
- PCB Stack-Up Information: https://www.sfcircuits.com/pcb-production-capabilities/pcb-stack-up
- PCB Manufacturer that will be used for this project (JLCPCB) -https://jlcpcb.com/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 (https://jlcpcb.com/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)

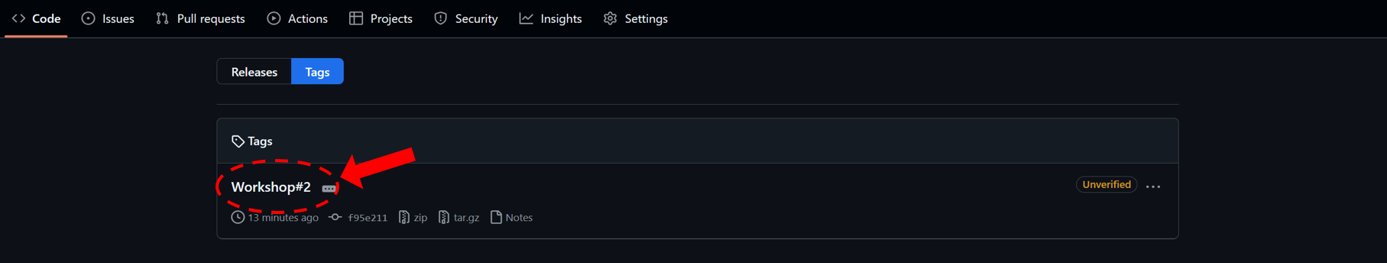
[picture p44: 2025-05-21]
images/download_source_step2.png

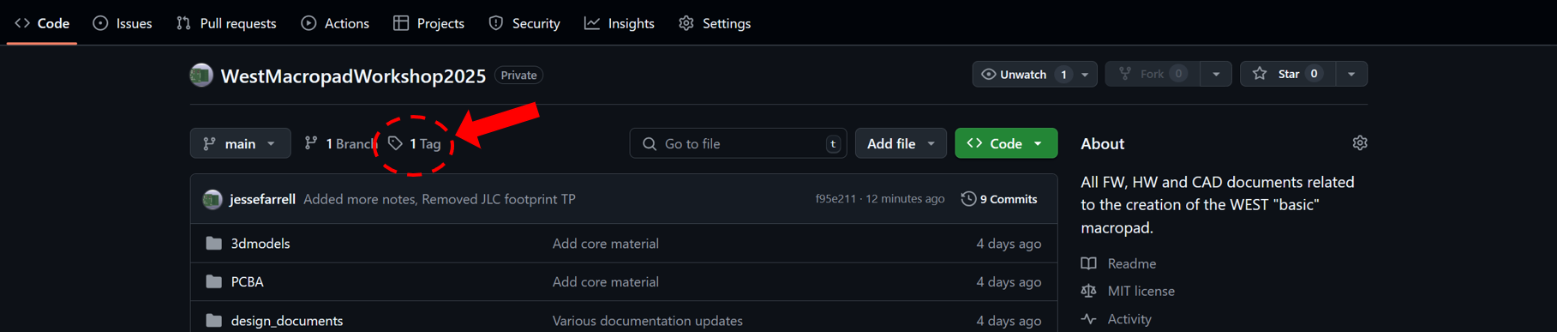
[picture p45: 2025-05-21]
images/download_source_step1.png

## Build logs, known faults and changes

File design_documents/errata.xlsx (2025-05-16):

Item # | Severity [0-5] | Short Description | Long Description | Action Items | Status | Date Added | Date Resolved | Result
1 | 4 | Isolation Vertical Distance |  | 1) Research vertical CC requirements 2) Remove cu on L2 pour above ETHx_LED signals. | PENDING | 2024-11-02
2
3
4
5
6
7
8
9
10
11
12
13

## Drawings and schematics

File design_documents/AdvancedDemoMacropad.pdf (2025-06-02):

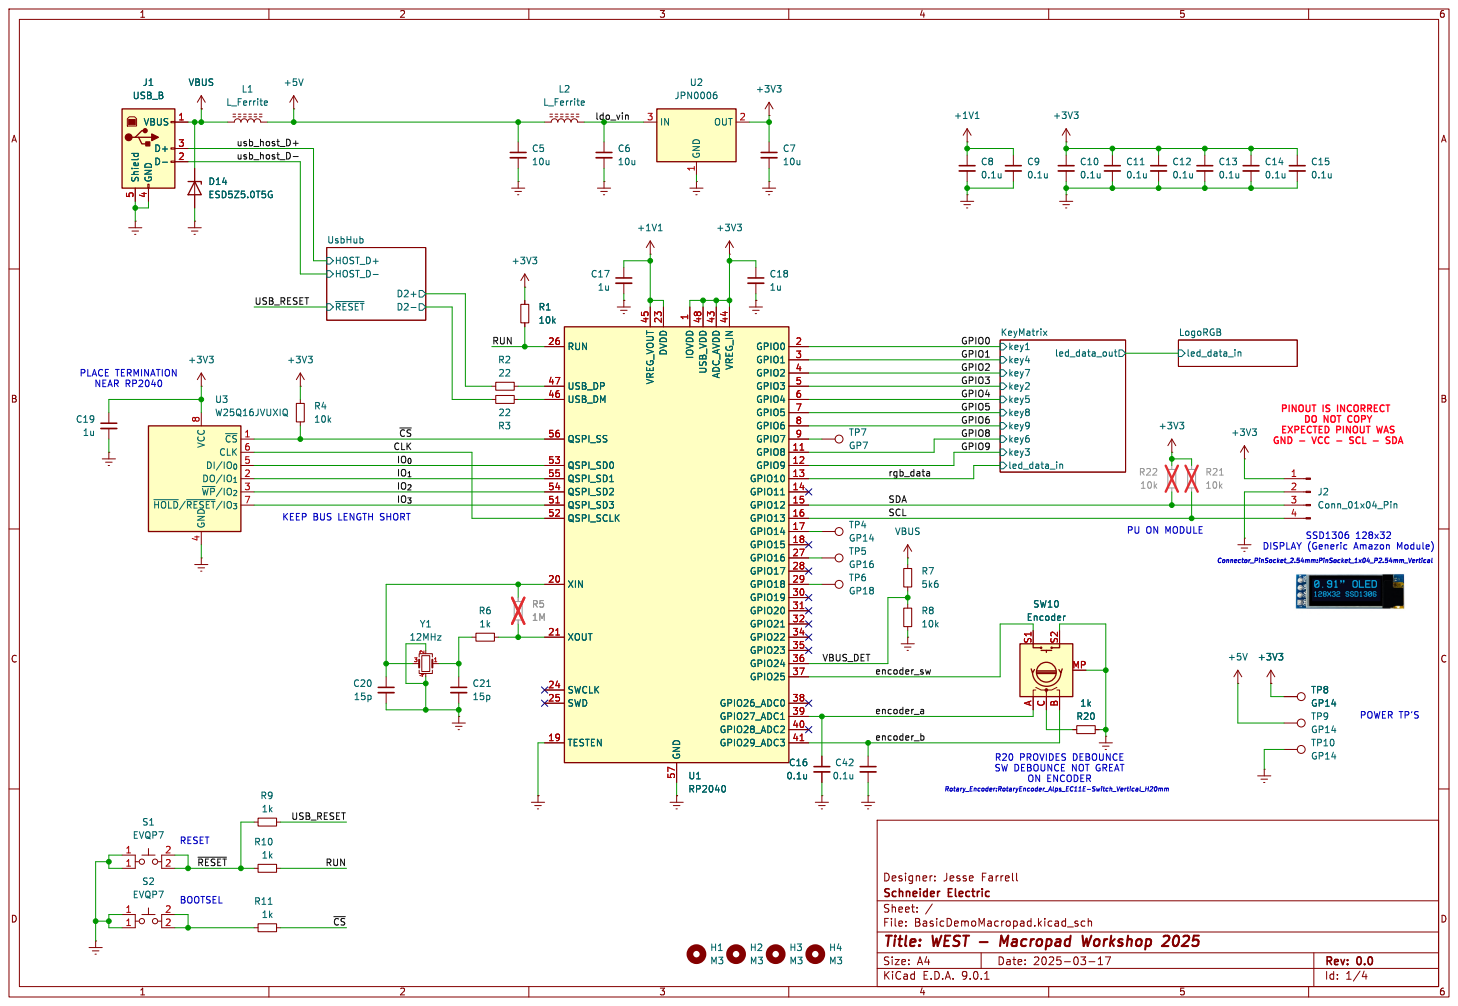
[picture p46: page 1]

~{CS}1 CLK 6 DI/IO_{0}5 DO/IO_{1}2 ~{WP}/IO_{2} 3 ~{HOLD}/~{RESET}/IO_{3} 7 VCC

EXPECTED PINOUT WAS GND - VCC - SCL - SDA

Connector_PinSocket_2.54mm:PinSocket_1x04_P2.54mm_Vertical SSD1306 128x32 DISPLAY (Generic Amazon Module) Rotary_Encoder:RotaryEncoder_Alps_EC11E-Switch_Vertical_H20mm RESET

R20 PROVIDES DEBOUNCE
SW DEBOUNCE NOT GREAT ON ENCODER

Id: 1/4 Title: WEST - Macropad Workshop 2025

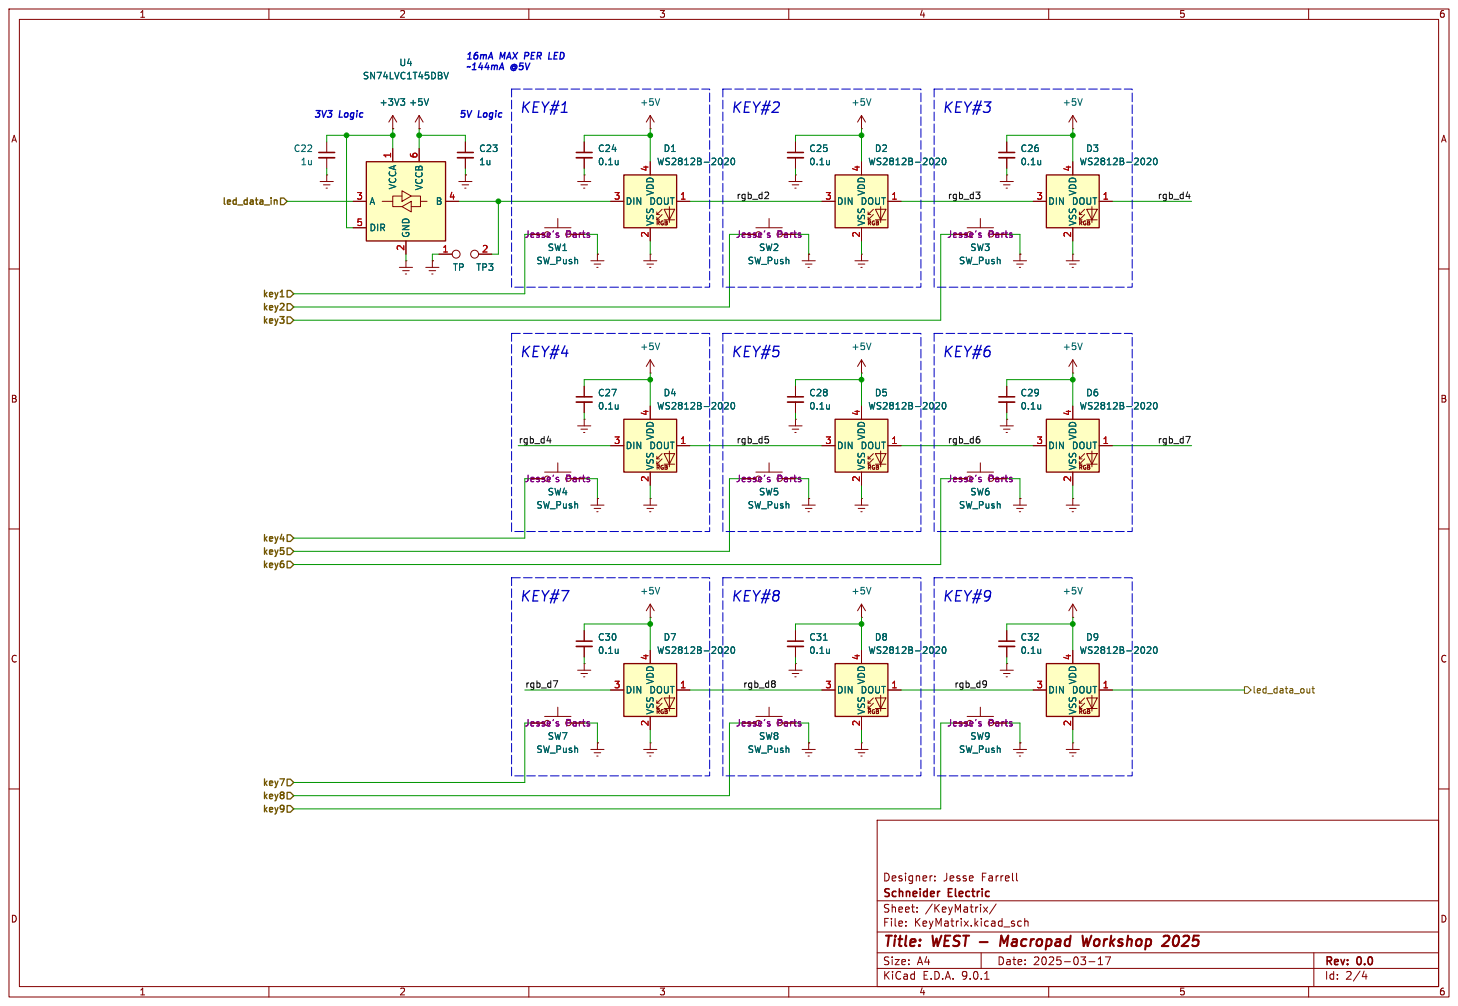
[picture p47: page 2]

Id: 2/4 Title: WEST - Macropad Workshop 2025

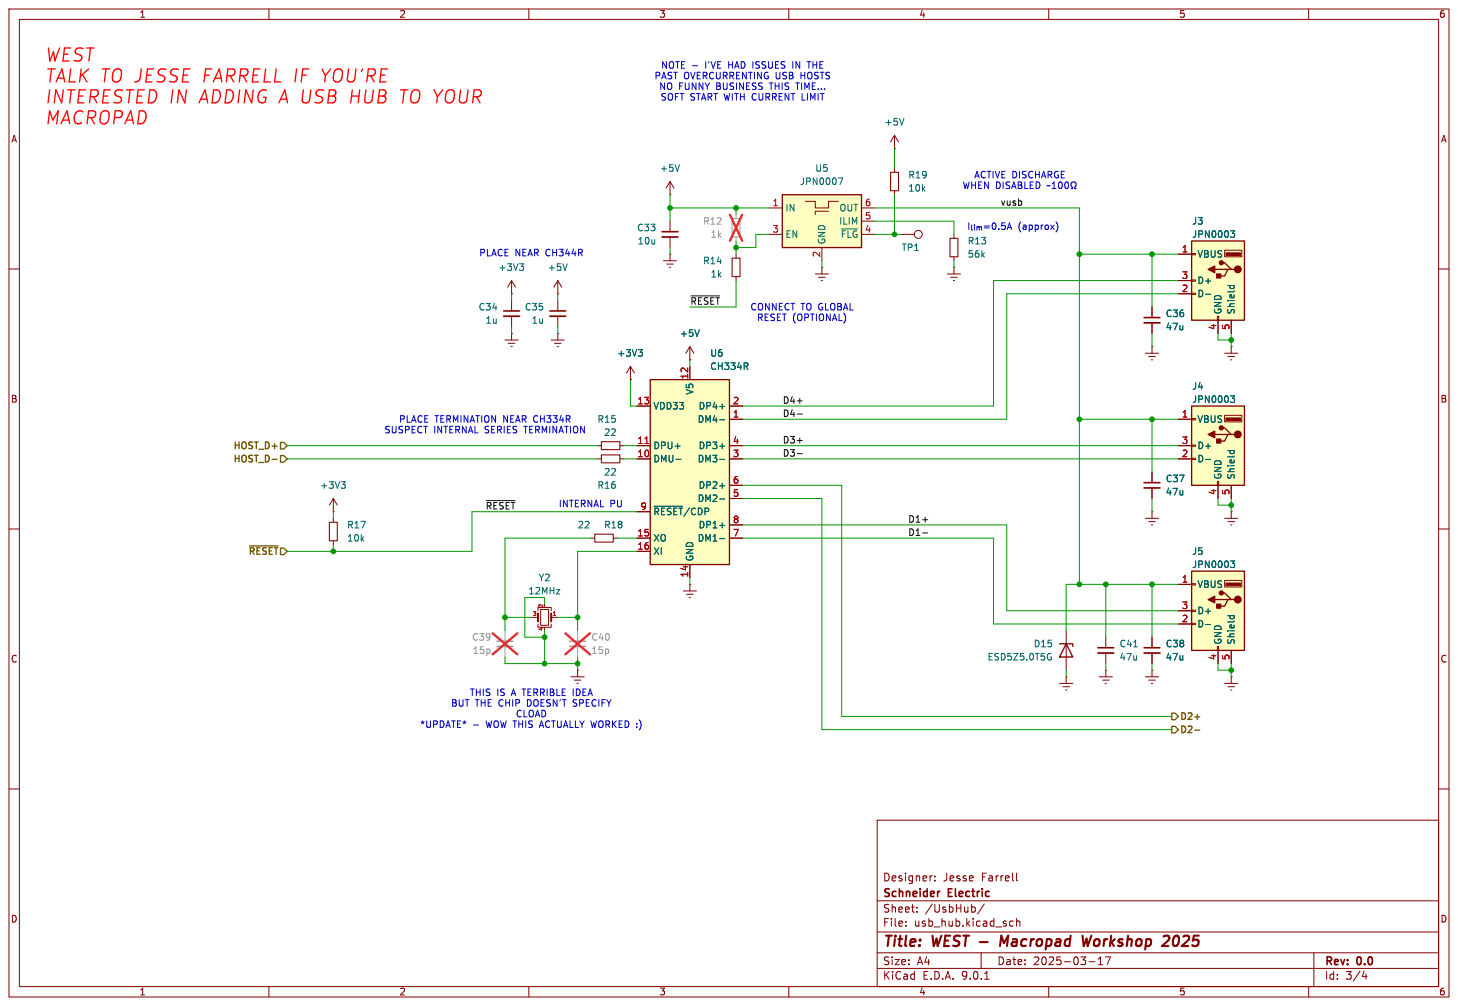
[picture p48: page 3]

INTERNAL PU WEST
TALK TO JESSE FARRELL IF YOU'RE
INTERESTED IN ADDING A USB HUB TO YOUR
MACROPAD

NOTE - I'VE HAD ISSUES IN THE

I_{lim}=0.5A(approx) THIS IS A TERRIBLE IDEA

PLACE TERMINATION NEAR CH334R
SUSPECT INTERNAL SERIES TERMINATION

BUT THE CHIP DOESN'T SPECIFY CLOAD

Id: 3/4 Title: WEST - Macropad Workshop 2025

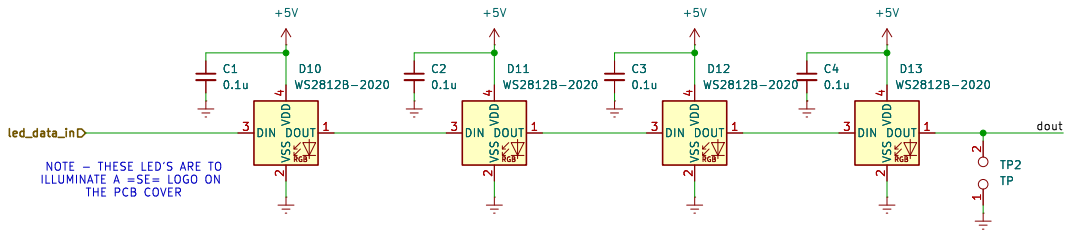
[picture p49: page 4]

dout NOTE - THESE LED'S ARE TO
led_data_in

ILLUMINATE A =SE= LOGO ON

Id: 4/4 Title: WEST - Macropad Workshop 2025

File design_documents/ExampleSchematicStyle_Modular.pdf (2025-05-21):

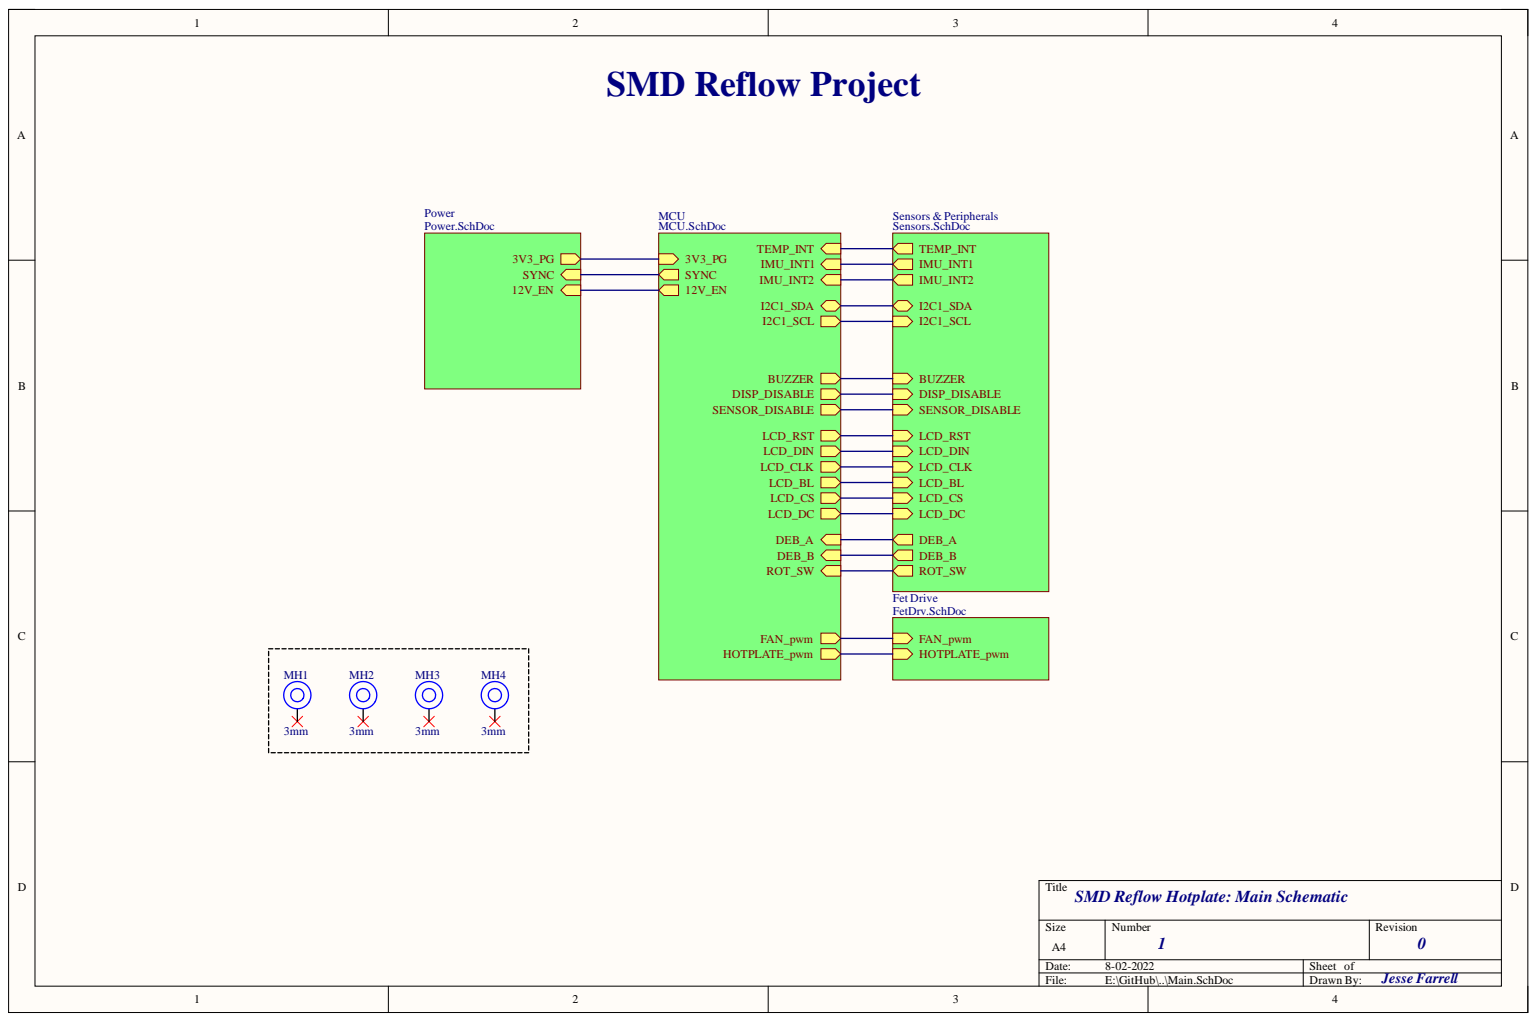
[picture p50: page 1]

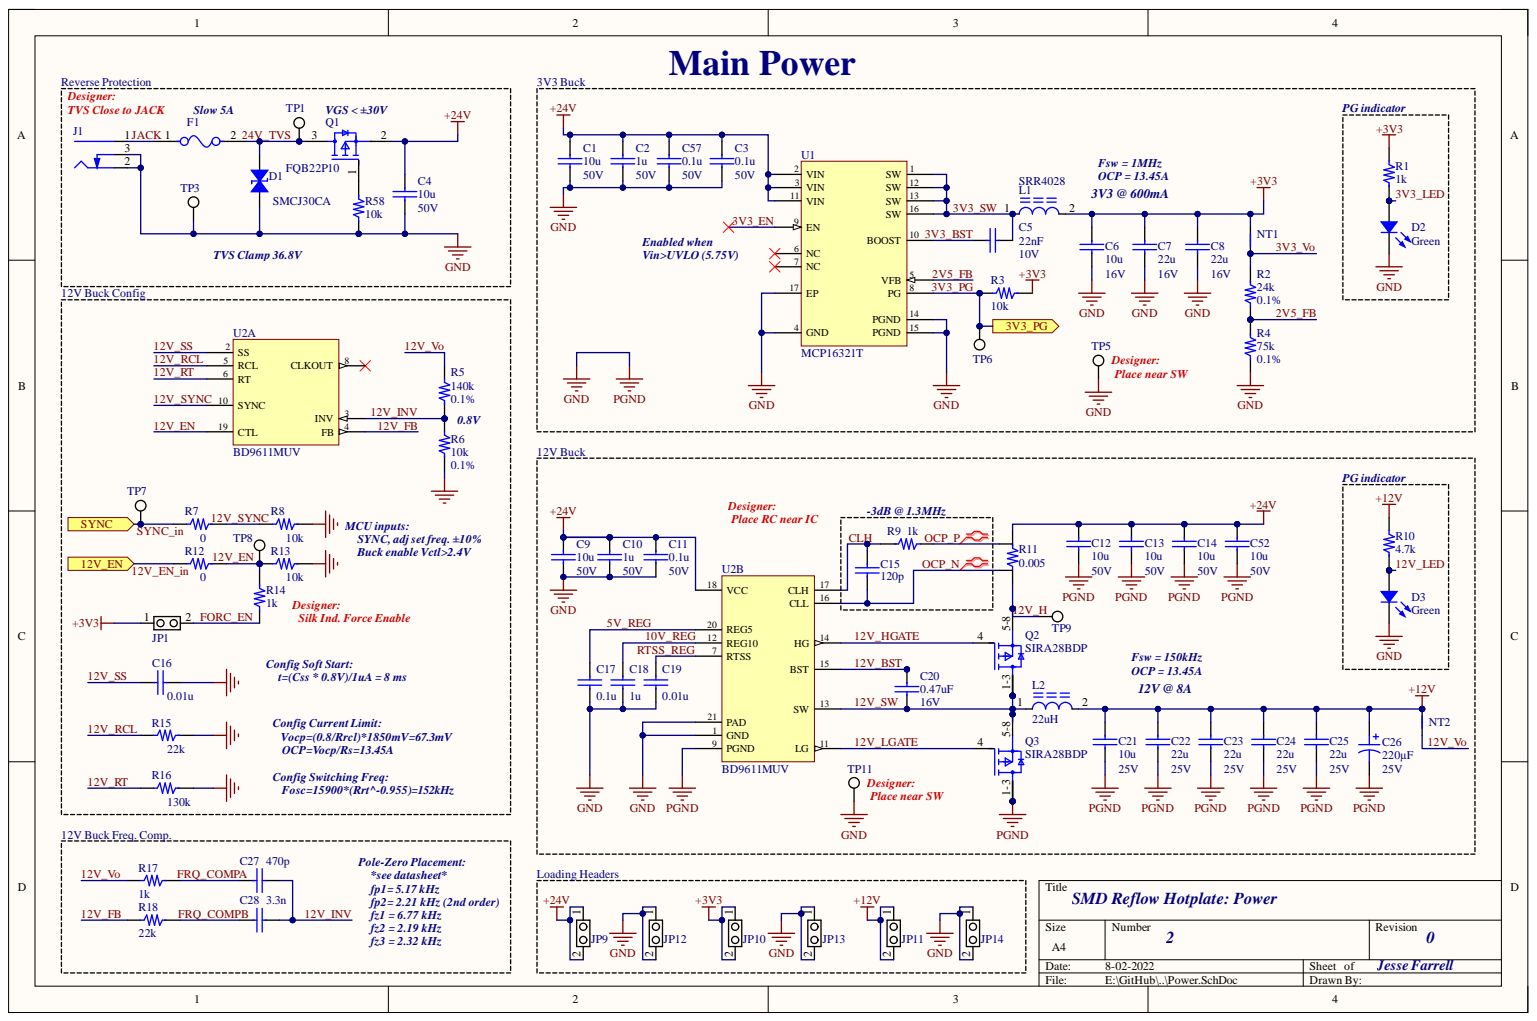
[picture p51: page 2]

Reverse Protection
Designer:
TVS Close to JACK

Place RC near IC

MCU inputs:
SYNC, adj set freq. ±10%
Buck enable Vctl>2.4V

10V_REG | RTSS 7 REG10 12 REG5 20

RTSS_REG | | 12V_BST

Title
SMD Reflow Hotplate: Power

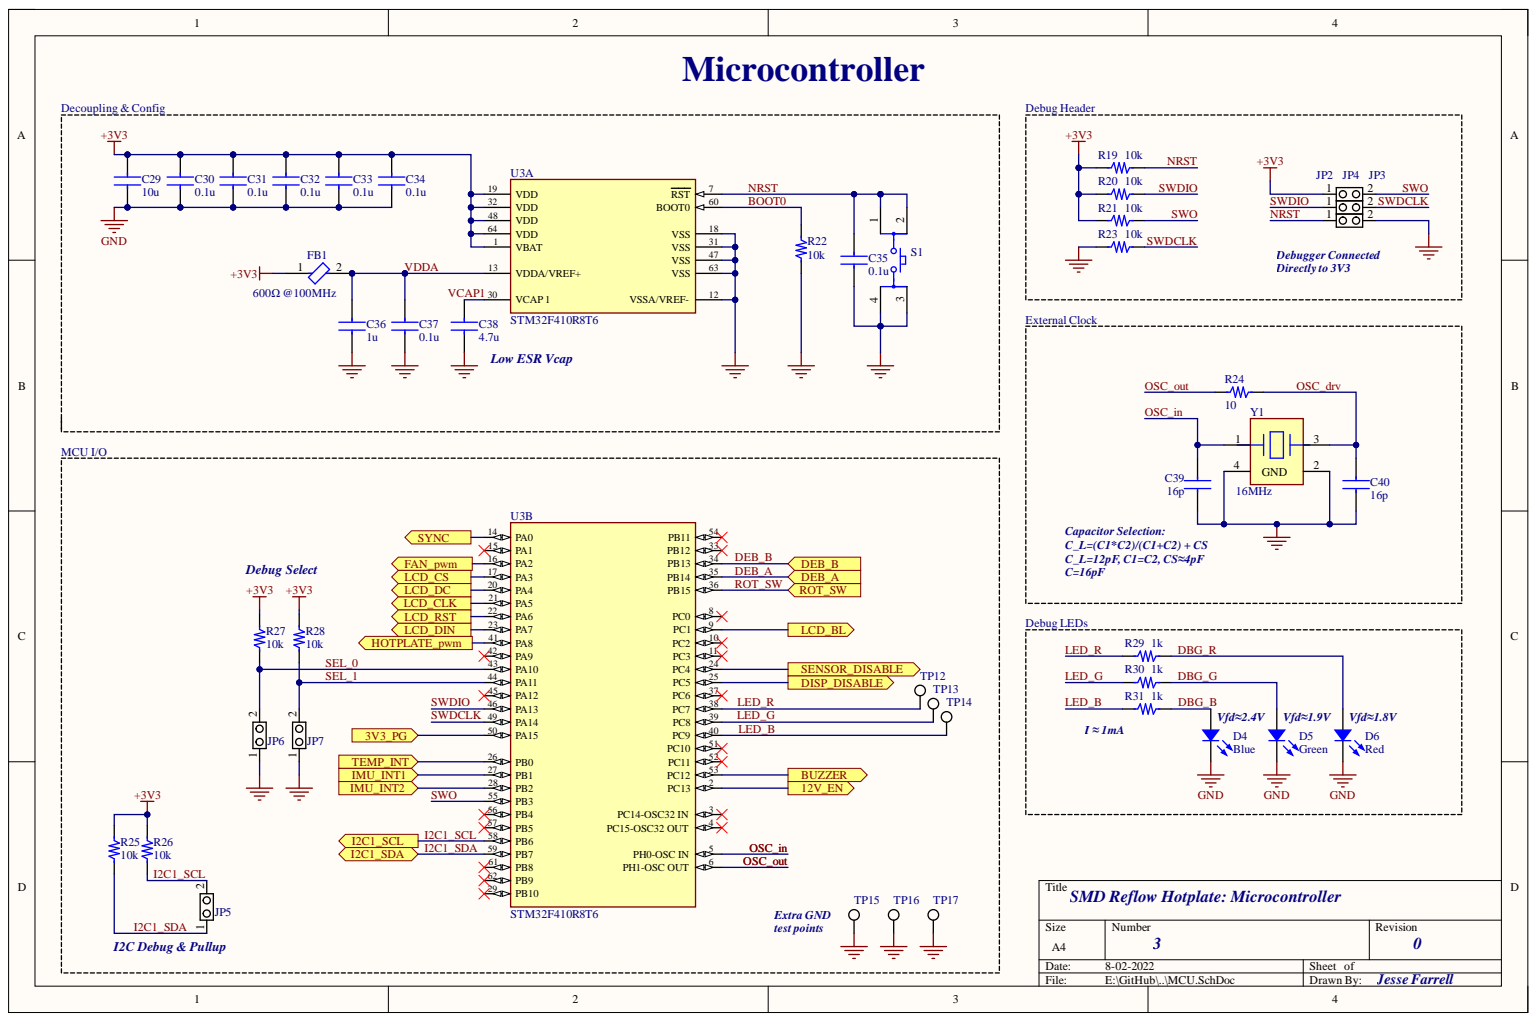
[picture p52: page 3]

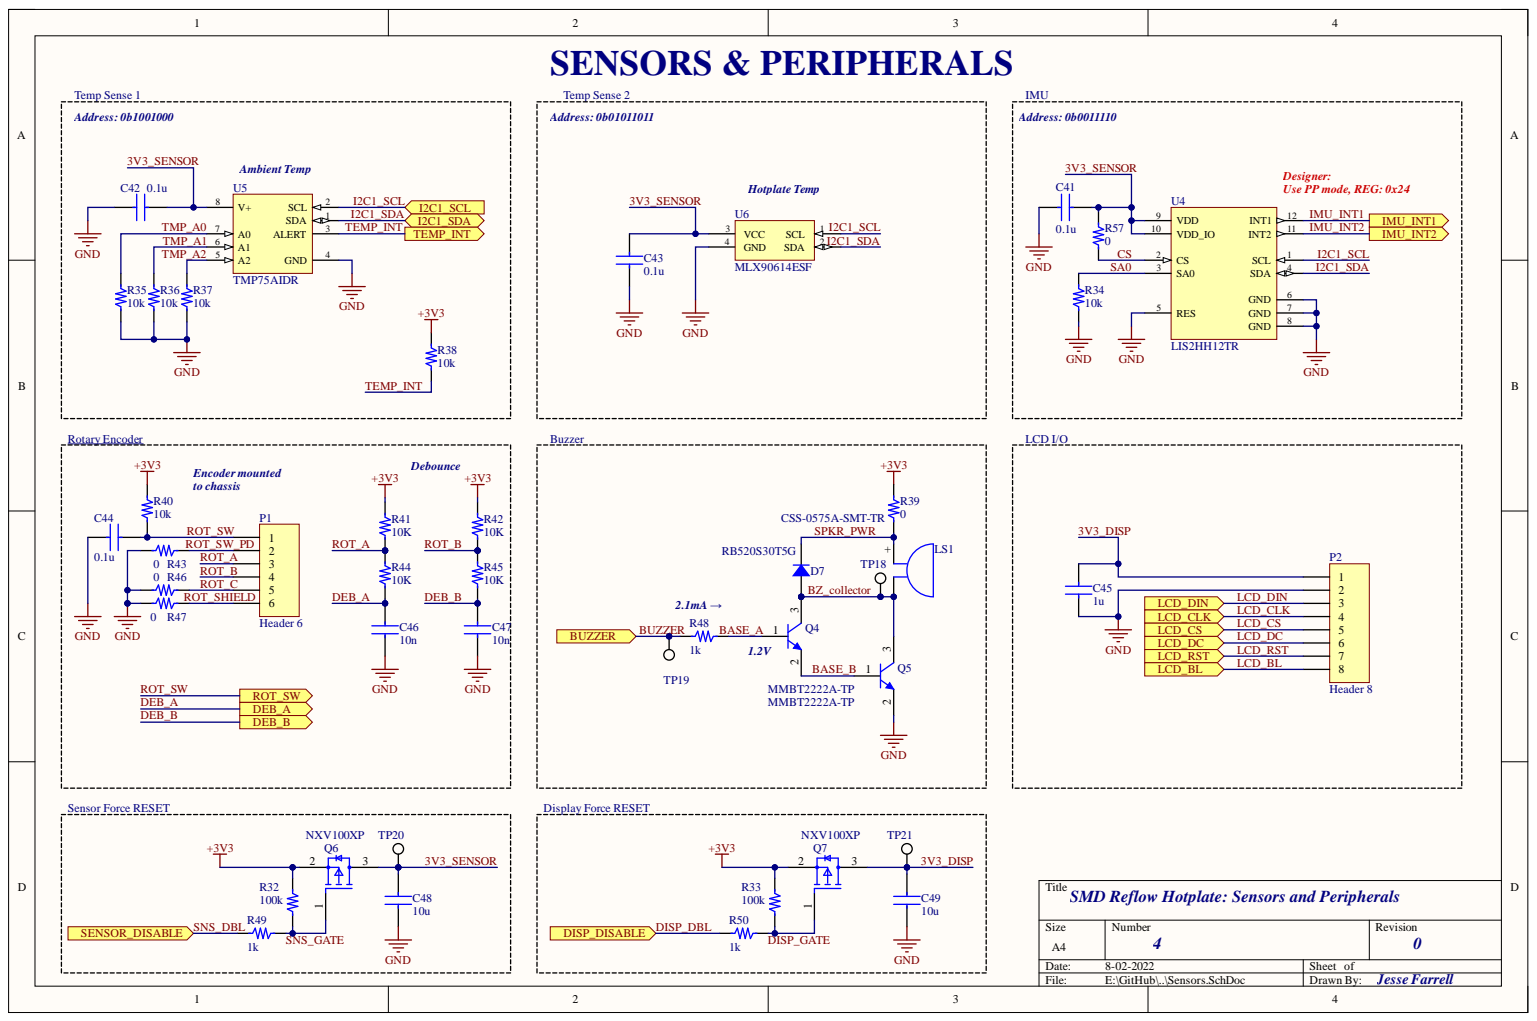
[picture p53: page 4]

Designer:
Use PP mode, REG: 0x24

Title
SMD Reflow Hotplate: Sensors and Peripherals

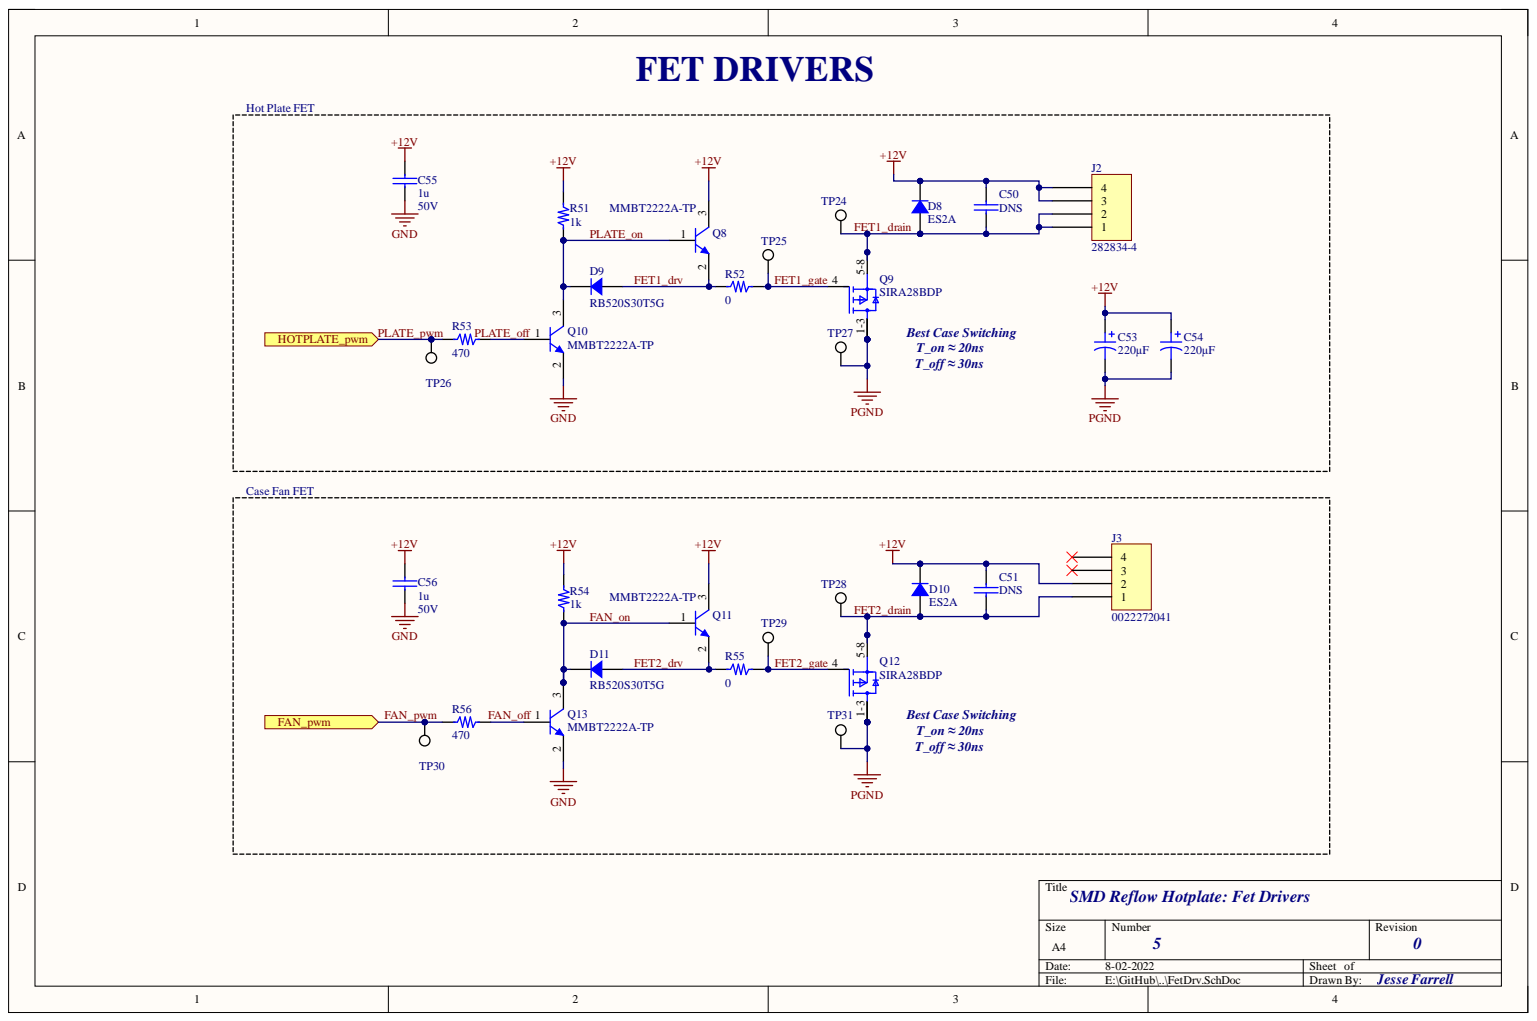
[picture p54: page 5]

Title
SMD Reflow Hotplate: Fet Drivers

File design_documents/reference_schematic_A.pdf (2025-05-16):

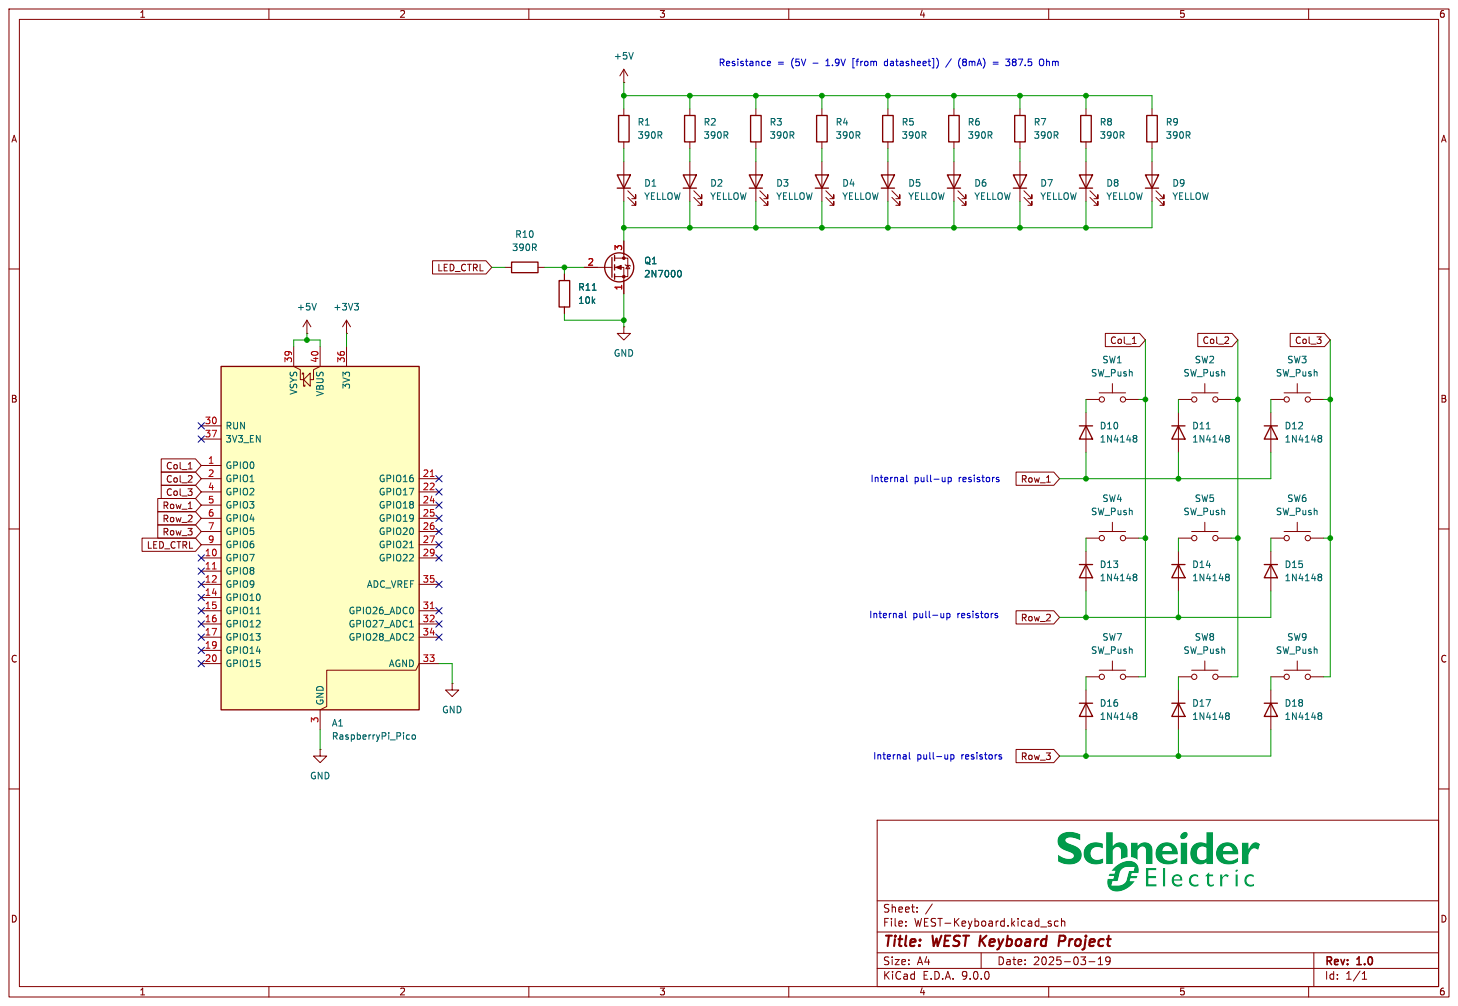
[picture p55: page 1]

Id: 1/1 Title: WEST Keyboard Project File: WEST-Keyboard.kicad_sch Sheet: /

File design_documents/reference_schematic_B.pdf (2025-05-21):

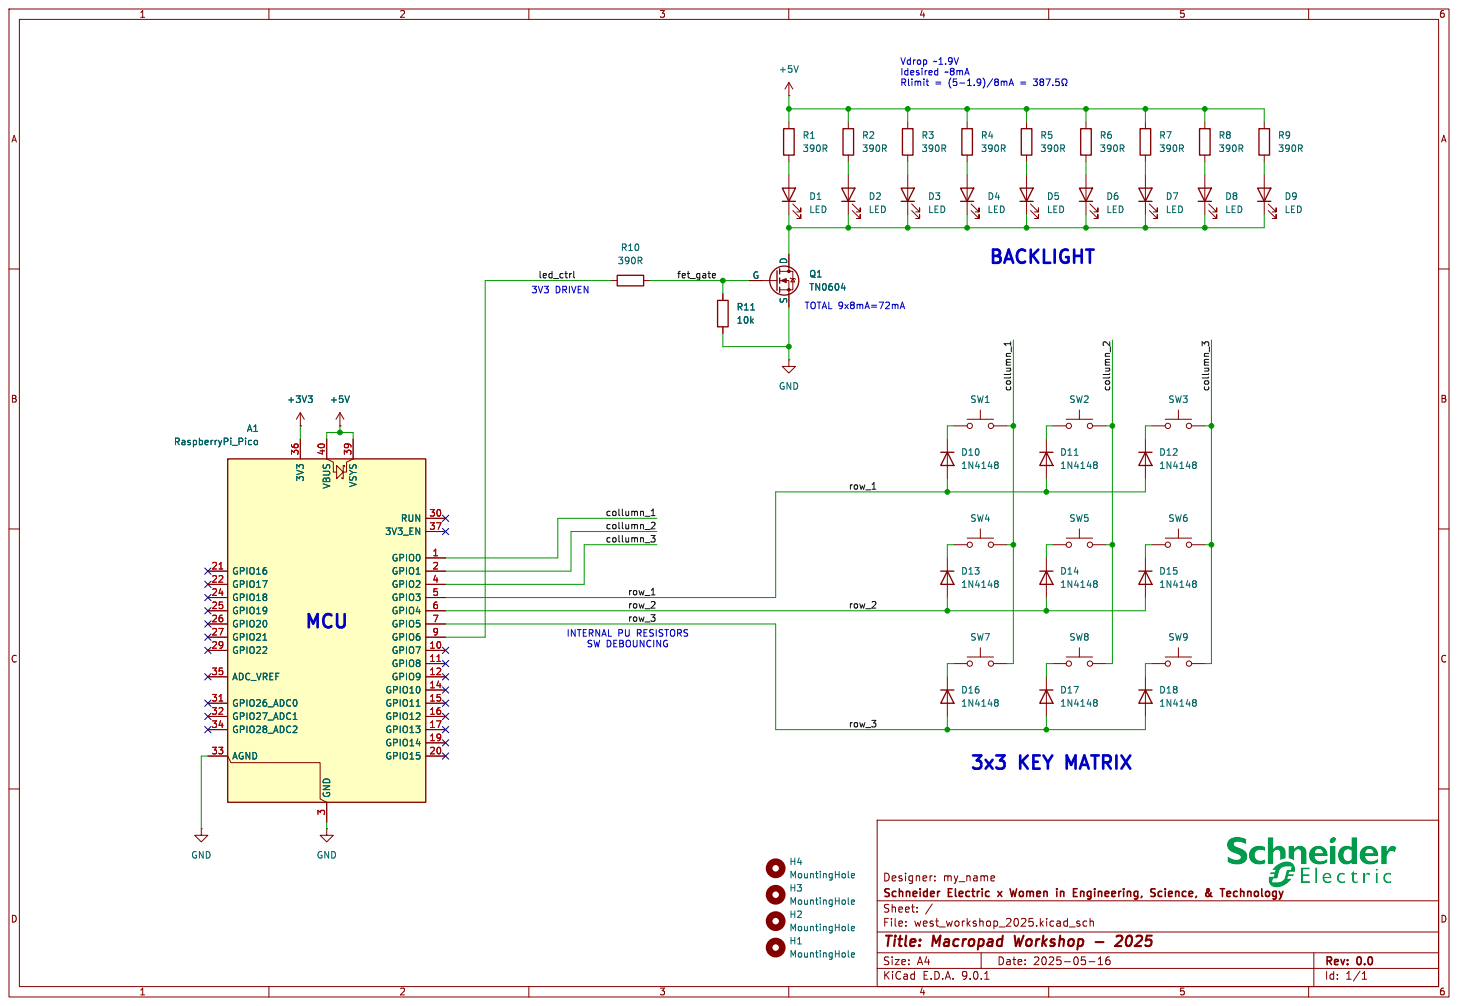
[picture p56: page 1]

Id: 1/1 Title: Macropad Workshop - 2025

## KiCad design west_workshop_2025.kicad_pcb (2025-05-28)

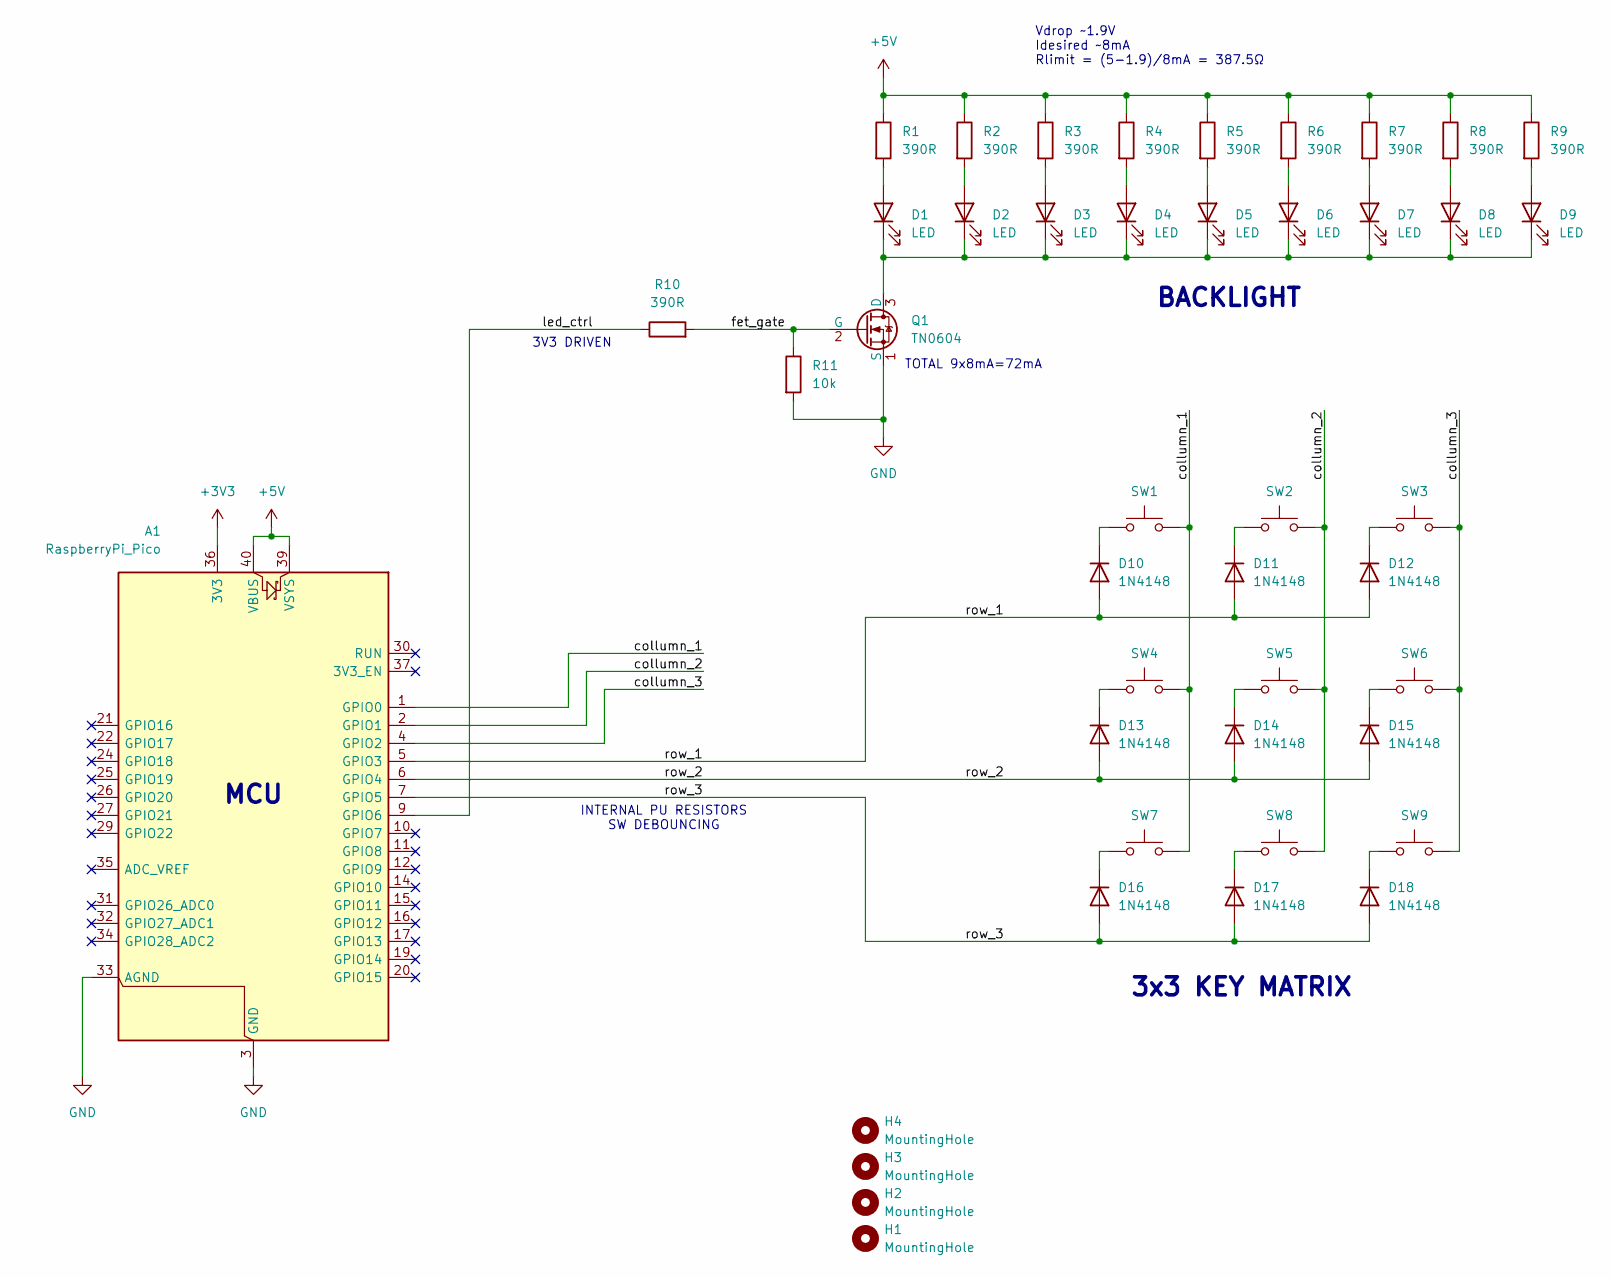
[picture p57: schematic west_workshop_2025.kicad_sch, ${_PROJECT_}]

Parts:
A1: RaspberryPi_Pico
D1, D2, D3, D4, D5, D6, D7, D8, D9: LED; Kingbright_WP914x
D10, D11, D12, D13, D14, D15, D16, D17, D18: 1N4148; D_DO-35_SOD27_P7.62mm_Horizontal
H1, H2, H3, H4: MountingHole; MountingHole_M2
Q1: TN0604; TO-92L_Inline
R1, R2, R3, R4, R5, R6, R7, R8, R9, R10: 390R; R_Axial_DIN0204_L3.6mm_D1.6mm_P5.08mm_Horizontal
R11: 10k; R_Axial_DIN0204_L3.6mm_D1.6mm_P5.08mm_Horizontal
SW1, SW2, SW3, SW4, SW5, SW6, SW7, SW8, SW9: switch_1.00u; SW_Cherry_MX_PCB_1.00u

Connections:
+3V3: A1.36 (3V3)
+5V: A1.39 (VSYS), A1.40 (VBUS), R1.1, R2.1, R3.1, R4.1, R5.1, R6.1, R7.1, R8.1, R9.1
/collumn_1: A1.1 (GPIO0), SW1.2, SW4.2, SW7.2
/collumn_2: A1.2 (GPIO1), SW2.2, SW5.2, SW8.2
/collumn_3: A1.4 (GPIO2), SW3.2, SW6.2, SW9.2
/fet_gate: Q1.2 (G), R10.2, R11.1
/led_ctrl: A1.9 (GPIO6), R10.1
/row_1: A1.5 (GPIO3), D10.2 (A), D11.2 (A), D12.2 (A)
/row_2: A1.6 (GPIO4), D13.2 (A), D14.2 (A), D15.2 (A)
/row_3: A1.7 (GPIO5), D16.2 (A), D17.2 (A), D18.2 (A)
GND: A1.3 (GND), A1.8 (GND), A1.13 (GND), A1.18 (GND), A1.23 (GND), A1.28 (GND), A1.33 (AGND), A1.38 (GND), Q1.1 (S), R11.2
unnamed: D1.2 (A), R1.2
unnamed: D1.1 (K), D2.1 (K), D3.1 (K), D4.1 (K), D5.1 (K), D6.1 (K), D7.1 (K), D8.1 (K), D9.1 (K), Q1.3 (D)
unnamed: D2.2 (A), R2.2
unnamed: D3.2 (A), R3.2
unnamed: D4.2 (A), R4.2
unnamed: D5.2 (A), R5.2
unnamed: D6.2 (A), R6.2
unnamed: D7.2 (A), R7.2
unnamed: D8.2 (A), R8.2
unnamed: D9.2 (A), R9.2
unnamed: D10.1 (K), SW1.1
unnamed: D11.1 (K), SW2.1
unnamed: D12.1 (K), SW3.1
unnamed: D13.1 (K), SW4.1
unnamed: D14.1 (K), SW5.1
unnamed: D15.1 (K), SW6.1
unnamed: D16.1 (K), SW7.1
unnamed: D17.1 (K), SW8.1
unnamed: D18.1 (K), SW9.1

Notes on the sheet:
MCU
3V3 DRIVEN
3x3 KEY MATRIX
BACKLIGHT
TOTAL 9x8mA=72mA
Vdrop ~1.9V Idesired ~8mA Rlimit = (5-1.9)/8mA = 387.5Ω
INTERNAL PU RESISTORS SW DEBOUNCING

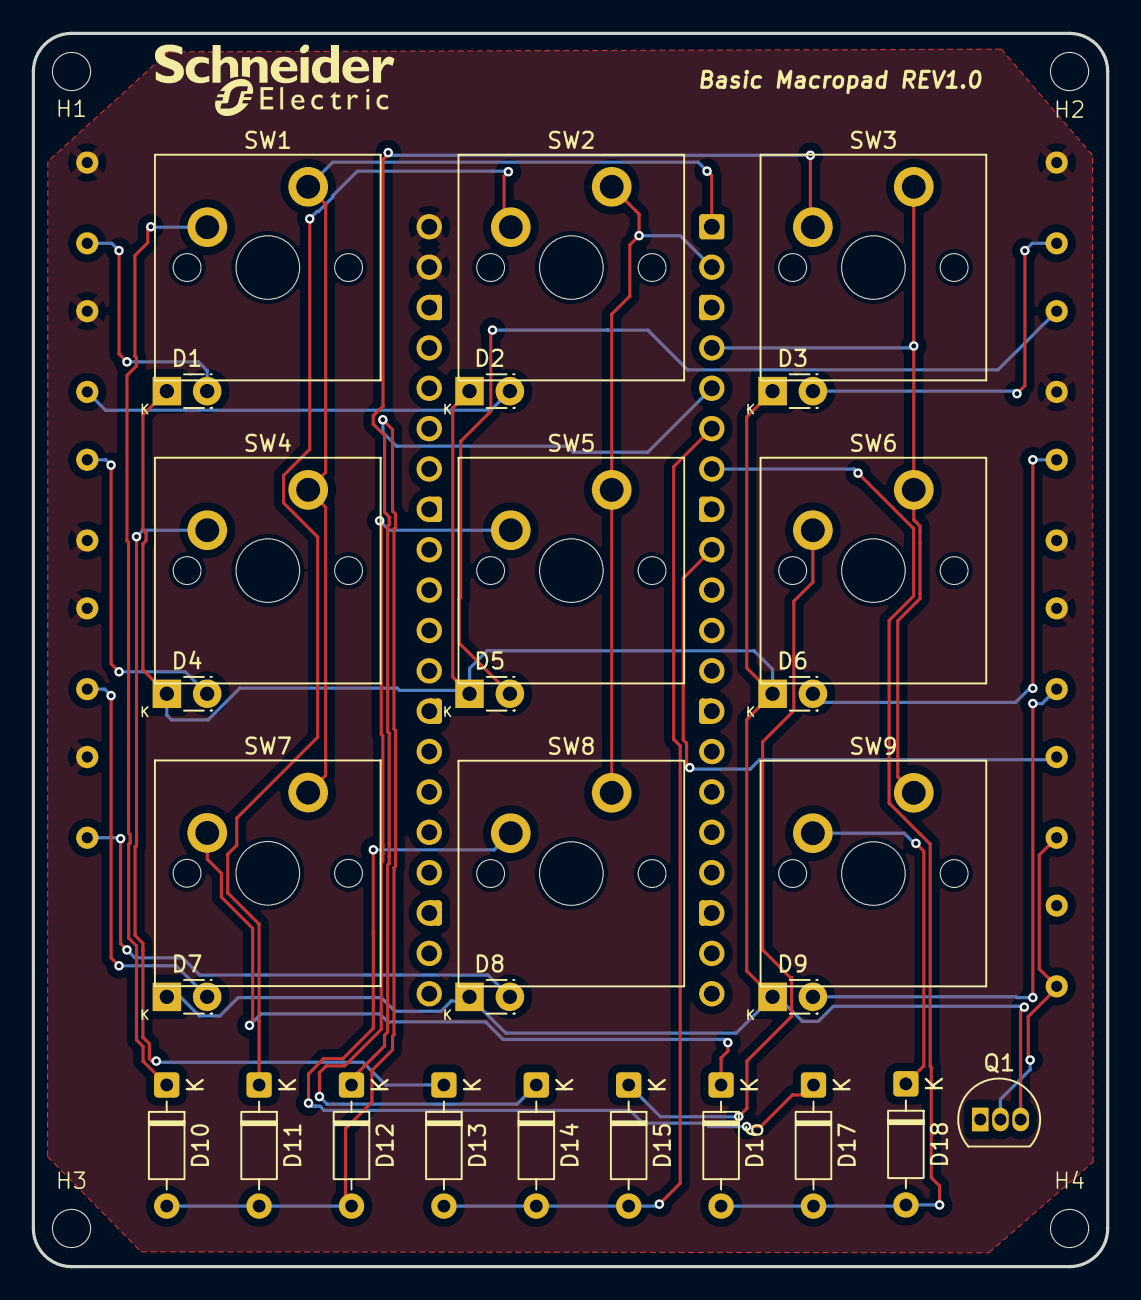
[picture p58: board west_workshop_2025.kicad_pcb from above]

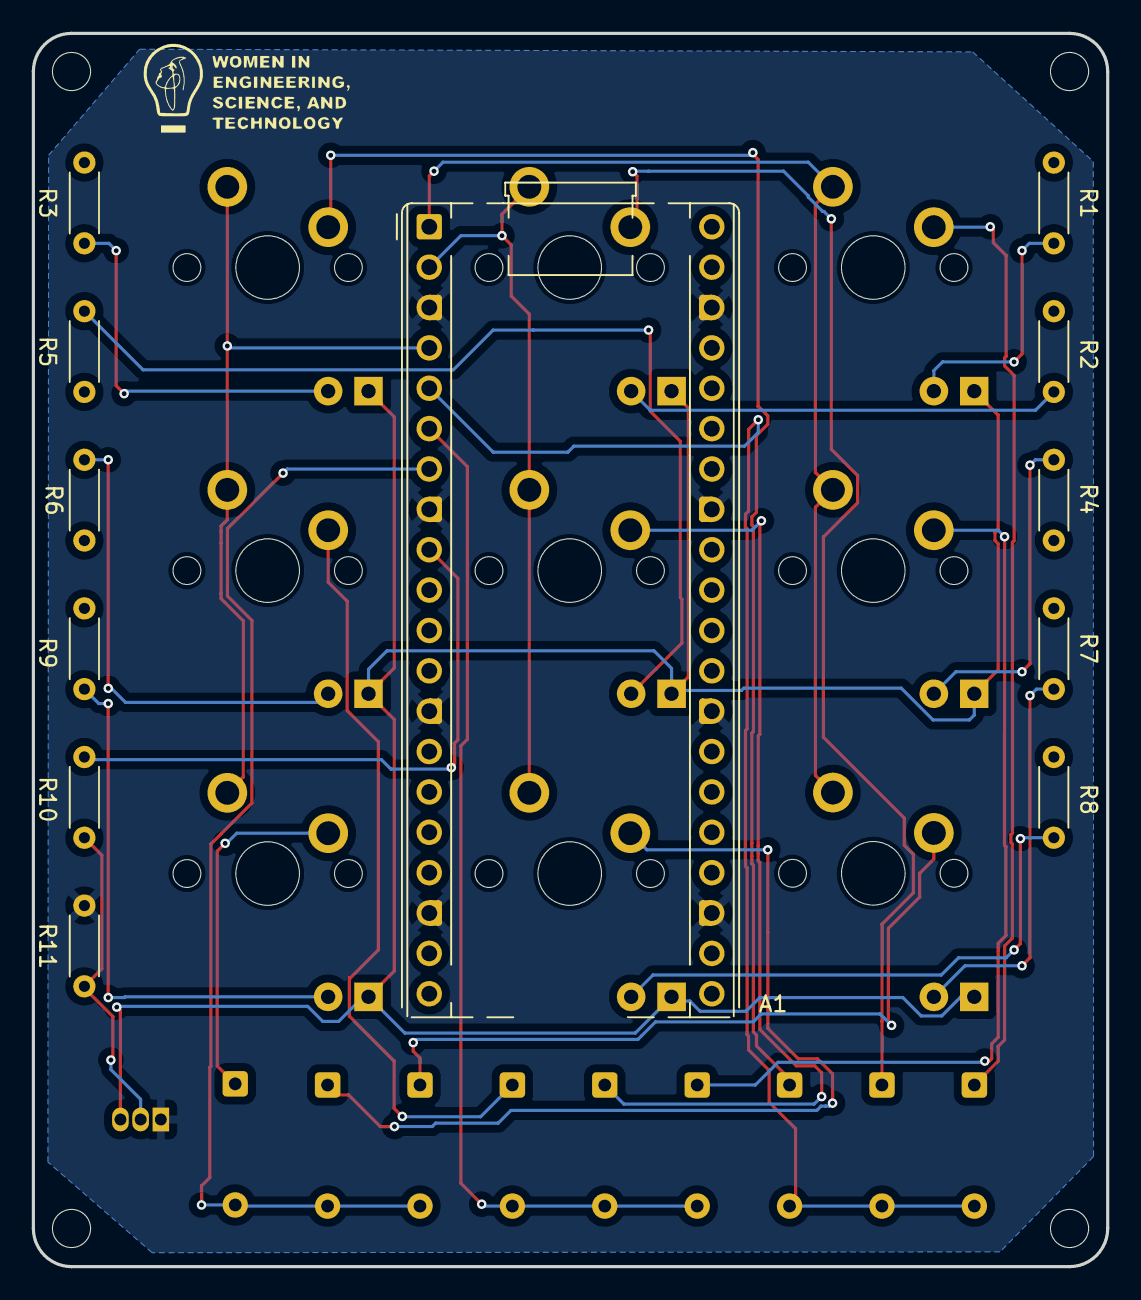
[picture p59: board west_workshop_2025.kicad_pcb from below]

Board: 4 copper layers, 67.6 x 77.6 mm, 44 parts (12 on the bottom side), 29 nets.

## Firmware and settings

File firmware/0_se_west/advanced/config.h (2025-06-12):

/* Copyright 2020 xxx
 *
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
 * You should have received a copy of the GNU General Public License
 * along with this program.  If not, see <http://www.gnu.org/licenses/>.
 */
#pragma once
// Rotational encoder
// #define ENCODER_A_PINS { GP27 }
// #define ENCODER_B_PINS { GP28 }
#define ENCODER_RESOLUTION 5 
#define ENCODER_MAP_KEY_DELAY 1  
#define ENCODER_DIRECTION_FLIP   // Uncomment to flip the direction of the encoder

// OLED Setup
#define I2C_DRIVER I2CD0    // This is our i2c isntance ()
#define I2C1_SCL_PIN GP13
#define I2C1_SDA_PIN GP12
#define OLED_DISPLAY_ADDRESS 0x3C
#define OLED_DISPLAY_128X32

// SE Logo
#define RGBLIGHT_LAYERS

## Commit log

2025-05-16 Add core material
    > Lots of background documentation added
    > Project configured for JLCPCB (ie. DRC)
    > Placed mounting holes and JLC order number on schematic just so we have a starting point
    [Keycap.STEP, Kingbright_WP914x_(Exact).STEP, Kingbright_WP914x_(Similar).step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]
2025-05-16 Various documentation updates
    > Add simulations
    > Change project name
    > Lots of readme
    [west_workshop_2025.kicad_pcb, west_workshop_2025.kicad_sch]
2025-05-20 Various Updates
    [west_workshop_2025.kicad_sch]
2025-05-21 Changed footprint library: global --> project
    > this makes it so students don't need to import libraries anymore
    > Path info is stored in the fp/sym-lib-table files
2025-05-21 Cleaned schematic --blank--
    [west_workshop_2025.kicad_sch]
2025-05-21 Added more notes, Removed JLC footprint TP
    [west_workshop_2025.kicad_sch]
2025-05-21 Add diode symbol
2025-05-21 Schematic Done - Ready for layout
    [west_workshop_2025.kicad_sch]
2025-05-21 Revert Change - Release issues
    [west_workshop_2025.kicad_sch]
2025-05-21 Schematic Done
    [west_workshop_2025.kicad_sch]
2025-05-21 Update west_workshop_2025.kicad_sch
    - Add Text
    [west_workshop_2025.kicad_sch]
2025-05-28 Correct NMOS pin numbering - IMPORTANT!!!!
2025-05-28 Create =SE= & WEST Logo Footprint
2025-05-28 Add Basic Macropad PCB Outline
    [Basic_PCB_outline.dxf]
2025-05-28 Minor Cleanup + NMOS Fix Applied
    [west_workshop_2025.kicad_sch]
2025-05-28 Clean PCB.
    [west_workshop_2025.kicad_pcb]
2025-05-28 Finished PCB
    [west_workshop_2025.kicad_pcb]
2025-05-30 Added advanced keypad Fusion model
    [Advanced-keypad-case v36.f3z]
2025-05-30 Moved fusion models out of 3dmodel folder
    [Advanced-keypad-case v36.f3z]
2025-06-02 Added info to rotary encoder and display
2025-06-02 Add footprint info for display header
2025-06-03 Updated advanced case design
    There was an issue with the .f3z in Fusion online. Had to redesign the part so it could be exported as an f3d (not an assembly).
    [Advanced-keypad-case v36.f3z, Advanced-keypad-case-MK2.f3d]
2025-06-11 Update readme.md
    changes to LED backlight section

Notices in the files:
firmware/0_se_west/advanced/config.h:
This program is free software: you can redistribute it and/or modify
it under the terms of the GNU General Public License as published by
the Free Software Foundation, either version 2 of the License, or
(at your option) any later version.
